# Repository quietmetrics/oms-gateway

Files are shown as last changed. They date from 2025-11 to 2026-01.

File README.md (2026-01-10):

## OMS Gateway (ESP32-C3 + CC1101)

This project is the firmware for an OMS/W‑MBus gateway running on ESP32‑C3 + CC1101.
It receives OMS telegrams via the CC1101, decodes the link‑layer structure, exposes a Web UI,
and forwards logical frames with metadata over Wi‑Fi to a backend.
The system overview below illustrates the data flow from the meter through the gateway to the backend,
then via MQTT into storage and dashboards/analytics.

### System Overview
```mermaid
flowchart LR
  classDef api fill:#d1fae5,stroke:#10b981,stroke-width:1px,color:#065f46;
  METER[OMS meter]
  subgraph GATEWAY_S[<b>Gateway]
    direction LR
    CC1101[CC1101 sub-GHz] <-->|SPI| ESP32[ESP32-C3 Wi-Fi]
  end
  METER -->|868MHz| CC1101
  subgraph BRIDGE_S[<b>Bridge]
    BRIDGE[Bridge Backend <br>FastAPI + Lobaro]
  end
  LOBARO[Lobaro API]
  LOBARO <-->|REST API| BRIDGE
  class LOBARO api;
  ESP32 -->|Wi-Fi / REST| BRIDGE
  BRIDGE -->|MQTT| STORE[Storage <br>Telegraf + InfluxDB]
  BRIDGE -->|MQTT| PROCESS_A[Real-time consumers]
  STORE -->|DB| PROCESS_B[Dashboards + analytics <br>Grafana]
```

### Key Concepts
- RF bytes are 3-of-6 coded on air; the firmware decodes and validates CRC16 blocks.
- The logical frame is CRC-free and starts at L; logical length = L+1, payload_len = L-10.
- The gateway forwards logical frames and metadata; decryption and application parsing happen in the backend.
- Parsing of decoded meter data is handled by [Lobaro](https://confluence.lobaro.com/display/PUB/wMbus+Parser), as shown in the system overview.
- The Web UI exposes live radio stats, frame metadata, and raw logical hex for external tools.

For a layer-by-layer breakdown of the OMS stack and code references see `doc/OMS_PROTOCOL_STACK.md`.

### Protocol Layers
| Protocol layers                                                                                                                               |
| --------------------------------------------------------------------------------------------------------------------------------------------- |
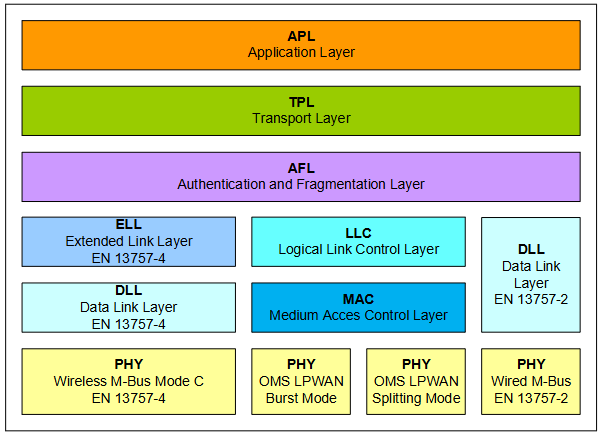
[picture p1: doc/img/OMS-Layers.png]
OMS protocol layers
|                                                                                                 |
| Diagram of the OMS stack we parse: PHY through DLL/ELL/TPL/AFL to APL, highlighting what the firmware extracts and what the backend finishes. |

### Encryption and Payload Strategy
- The gateway does not store keys and does not decrypt payloads.
- Transport/ELL/AFL parsing identifies where encrypted bytes sit in the logical frame.
- Full decoding is delegated to the backend.

### Web UI
Single-page UI for configuration and live monitoring.

| Web UI                                                                                                 |
| ------------------------------------------------------------------------------------------------------ |
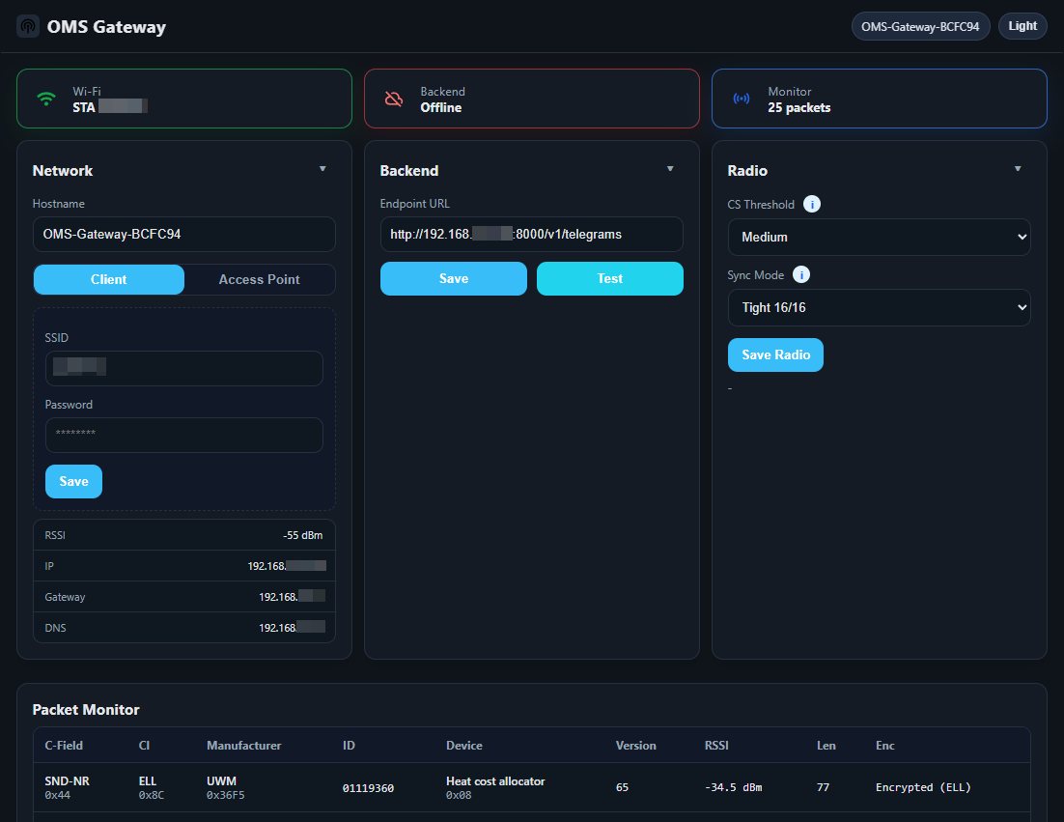
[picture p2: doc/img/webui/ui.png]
Web UI
|                                                                         |
| Main Web UI showing status cards, network/backend/radio controls, and quick device health at a glance. |

| Packet Monitor                                                                                           |
| -------------------------------------------------------------------------------------------------------- |
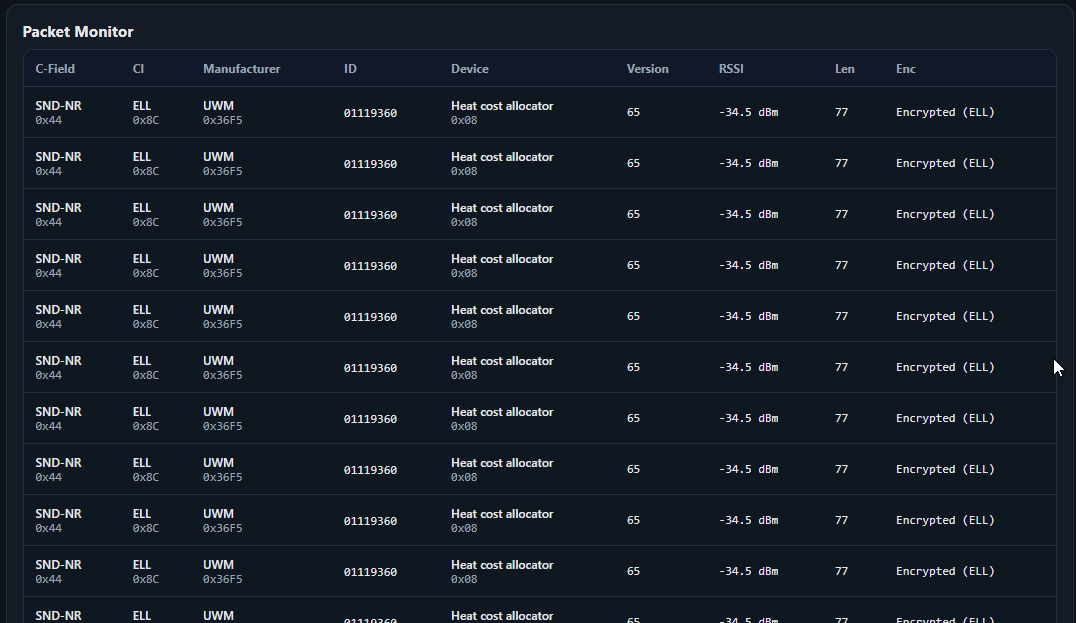
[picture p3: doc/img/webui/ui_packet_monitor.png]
Packet Monitor
|                                                    |
| Packet Monitor table with live frames, metadata, and quick indicators for encryption and signal quality. |

| Packet Details (Layers)                                                               |
| ------------------------------------------------------------------------------------- |
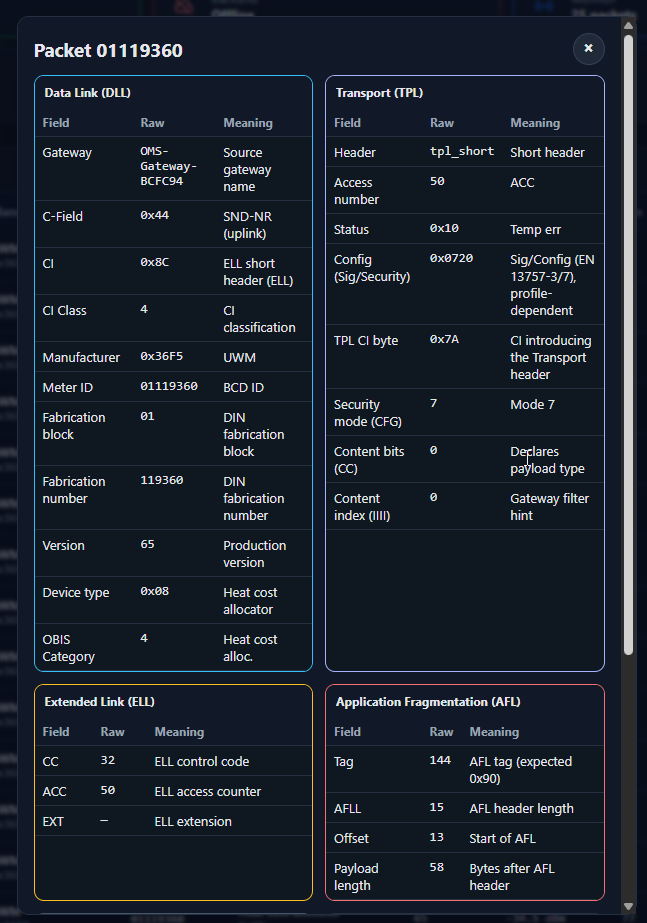
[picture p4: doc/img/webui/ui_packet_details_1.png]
Packet Details
|                               |
| Packet details dialog showing per-layer cards and parsed fields for a selected frame. |

| Packet Details (Raw)                                                           |
| ------------------------------------------------------------------------------ |
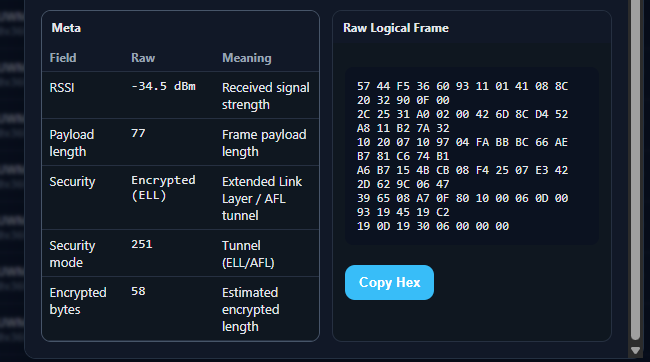
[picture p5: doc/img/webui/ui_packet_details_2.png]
Packet Details
|                        |
| Raw logical frame view with copy option for external tooling and verification. |

### Hardware
- ESP32-C3 (SuperMini form factor) + CC1101 868/886 MHz module.
- CC1101 breakout pinouts vary; use the TI datasheet as the wiring reference.

| Prototype hardware                                                                        |
| ----------------------------------------------------------------------------------------- |
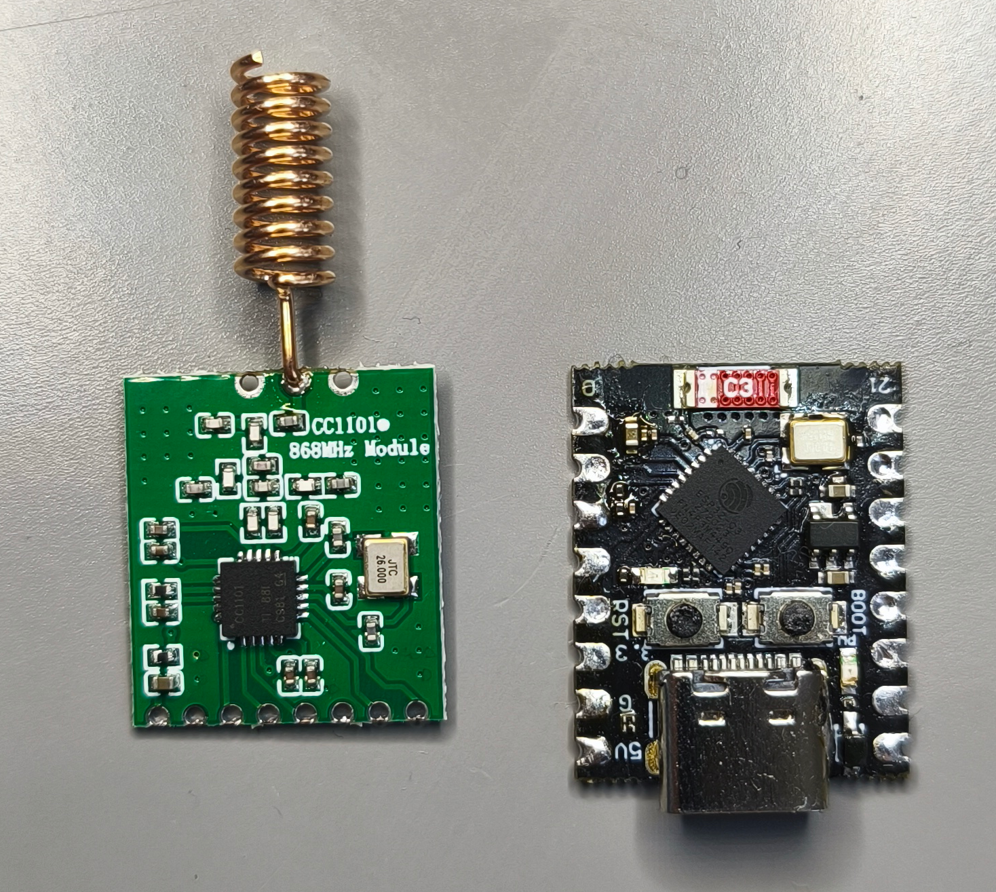
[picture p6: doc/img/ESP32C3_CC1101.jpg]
ESP32-C3 and CC1101
|                                         |
| Prototype hardware: ESP32-C3 board paired with a CC1101 module for sub-GHz OMS reception. |

| Connected prototype                                                    |
| ---------------------------------------------------------------------- |
| ESP32-C3 and CC1101 connected |
| Wiring between the ESP32-C3 and CC1101 during bring-up and RF testing. |

| Enclosure open | Enclosure with lid |
| --- | --- |
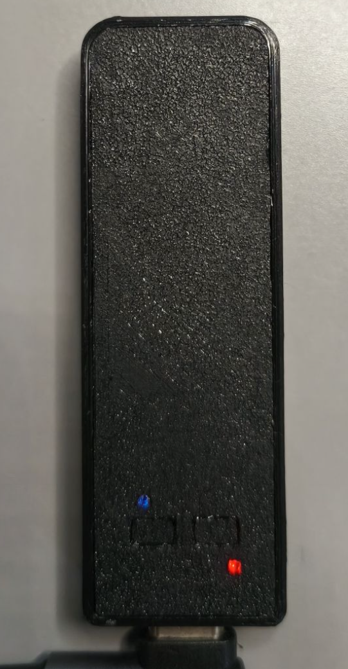
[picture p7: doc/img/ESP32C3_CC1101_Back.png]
Enclosure with lid
| Enclosure open |  |

### Requests (HTTP)
Outbound to backend (configured URL):
- Method: POST
- Content-Type: application/json
- Body example:
```json
{
  "gateway": "oms-gateway",
  "status": 0,
  "rssi": -67.5,
  "lqi": 103,
  "manuf": 3246,
  "id": "12345678",
  "dev_type": 7,
  "version": 1,
  "ci": 120,
  "payload_len": 77,
  "logical_hex": "2B44..."
}
```

Local device API (used by the Web UI):
- GET /api/status
- GET /api/packets
- POST /api/backend?url=...
- GET /api/backend/test?url=...
- POST /api/wifi?ssid=...&pass=...
- POST /api/ap?ssid=...&pass=...
- POST /api/radio?cs=...&sync=...
- See main/app/http_server.c for the full list.

### Quick build/flash
Run from repo root with ESP-IDF environment sourced:
```sh
idf.py set-target esp32c3    # one-time
idf.py build
idf.py -p /dev/ttyUSB0 flash
idf.py monitor
```
Adjust serial port as needed. Use `idf.py erase-flash` if NVS/config needs resetting.

### Repository Layout
- `main/app/`: runtime, services, Wi-Fi/backend forwarding, frame parsing, Web UI.
- `main/radio/`: CC1101 HAL, register presets, RX pipeline glue.
- `main/wmbus/`: OMS/W-MBus framing (3-of-6, CRC16), packet parsing, pipeline utilities.

### Packet Handling Flow (T-mode)
RX path (CC1101 to decoded packet):
- CC1101 strips preamble/sync and exposes 3-of-6 coded bytes in its RX FIFO.
- `wmbus_pipeline_receive` (`main/wmbus/pipeline.c`) reads the first coded bytes, decodes L-field, and sizes the packet.
- `wmbus_decode_rx_bytes_tmode` decodes the 3-of-6 stream and checks CRC16 blocks.
- If `rx_logical` is provided, CRC blocks are stripped and `frame_info` is filled for UI/backend use.

TX path (app to CC1101):
- Build a header (`wmbus_build_default_header`) or fill `WmbusFrameHeaderRaw`, then encode with `wmbus_encode_tx_packet_with_header`.
- `wmbus_encode_tx_bytes_tmode` converts raw packet bytes into 3-of-6 coded bytes.

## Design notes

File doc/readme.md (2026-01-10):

# OMS Gateway – Project Status and Key Concepts

> [!NOTE]
> This document summarizes the current state of the OMS Wireless M‑Bus Gateway
> and the main architectural ideas, from the meter in the field up to the
> dashboard.

> [!IMPORTANT]
> Repository structure update: this repo now focuses solely on the ESP-IDF
> firmware. The FastAPI backend lives in a dedicated repository
> ([oms-bridge](https://gitBridge.com/quietmetrics/oms-bridge)), ensuring both codebases can evolve
> independently while keeping their documentation close to the relevant code.

> [!TIP]
> Need a layer-by-layer breakdown of the OMS stack? See `doc/OMS_PROTOCOL_STACK.md`
> for a companion guide that mirrors OMS Volume 2 and references the codebase.

---

## 1. Goal and Scope

The OMS Wireless M‑Bus Gateway has four main goals:

* Receive **OMS Wireless Meter‑Bus frames** in the 868 / 886 MHz band with a
  **Texas Instruments CC1101 sub‑GHz transceiver (CC1101)**.
* Use an **Espressif ESP32‑C3 microcontroller (ESP32‑C3)** with Wi‑Fi as the
  central platform.
* Forward frames, metadata and encrypted payload to a **backend and database**.
* Provide a **web interface (Web UI)** for configuration and live monitoring.

Decryption and interpretation of meter readings are **not** performed on the
radio side. They are part of the **data processing pipeline** in the backend
and belong to the next development step together with the **Application Layer
(APL)** parsing.

---

## 2. End‑to‑End System Picture

### 2.1 Big Picture

```mermaid
flowchart LR
  OMS[OMS meter device]
  GW[OMS gateway]
  DB[Time series database]
  UI[Visualization dashboard]

  OMS --> GW --> DB --> UI
```

* The **OMS meter device** sends encrypted Wireless M‑Bus frames over the air.
* The **OMS gateway** receives the radio signal, decodes the protocol layers
  and forwards encrypted payload plus metadata.
* The **time series database** stores the data for long‑term analysis.
* The **visualization dashboard** shows trends, alarms and reports.

> [!NOTE] Current Build Status  
> - [x] Stable RF receive path (CC1101 HAL, Mode C timing, RSSI/LQI logging)  
> - [x] Layered parser (DLL → ELL → AFL → TPL) filling `wmbus_parsed_frame_t` for UI/backend  
> - [x] Web UI for Wi-Fi onboarding, radio presets, backend probe, live monitor  
> - [x] FastAPI backend stub ready for MQTT/InfluxDB forwarding  
> - [x] Active-low LED HAL for Wi-Fi/payload feedback on GPIO8  
> - [ ] Backend decryption + Application Layer parsing  
> - [ ] Finalize MQTT/InfluxDB bridge and RF-optimized hardware rev

### 2.2 OMS Protocol Layers

An overview of the protocol layers used in the project:

OMS protocol layers

The implementation focuses on:

* **Physical Layer (PHY)**
* **Data Link Layer (DLL)**
* **Transport Layer (TPL)** and **Extended Link Layer (ELL)**
* **Application Frame Layer (AFL)** and **Application Layer (APL)**

The gateway extracts the structure and metadata of these layers so that the
backend can apply decryption and application‑specific parsing.

### 2.3 Application Payload Strategy

OMS meters embed their readings in CI-dependent payloads (M‑Bus DIF/VIF trains,
DLMS/COSEM APDUs, SML frames, service protocols, etc.). Parsing those streams
requires a large, meter-specific knowledge base (storage slots, quantities,
descriptors). Instead of duplicating projects such as
[`wmbusmeters`](../EXAMPLE_WMBUSMASTER/wmbusmeters) on the ESP32 (which would
exceed the available flash/RAM and be hard to keep up to date), the firmware
currently forwards the entire logical frame to the backend/Web UI. The monitor
UI now exposes a raw-hex copy button so external tools can ingest exactly what
the gateway received. Full decoding is therefore expected to happen off-device
where mature, easily updateable drivers already exist.

---

## 3. Hardware Status

### 3.1 Main Components

| Component | Role in the gateway |
| --- | --- |
| **Espressif ESP32‑C3** | MCU platform with Wi‑Fi, USB‑C power, FreeRTOS runtime for radio control + Web UI. |
| **TI CC1101 (sub‑GHz)** | Frontend for OMS Mode C reception, SPI-connected with dedicated GPIO interrupts. |
| **Enclosure / CAD** | 3D-printed shell combining ESP32‑C3 + CC1101 for a repeatable lab setup. |

| ESP32‑C3 and CC1101 | Description |
| --- | --- |
| ESP32-C3 and CC1101 | First working prototype of the OMS gateway based on ESP32‑C3 and CC1101. |

> [!WARNING]
> Pinouts of low‑cost CC1101 breakout boards are inconsistent. The design uses
> the original Texas Instruments documentation as the primary reference for
> wiring and register configuration.

### 3.2 Wiring and Pinout

| ESP32‑C3 SuperMini pinout | CC1101 module pinout |
| --- | --- |
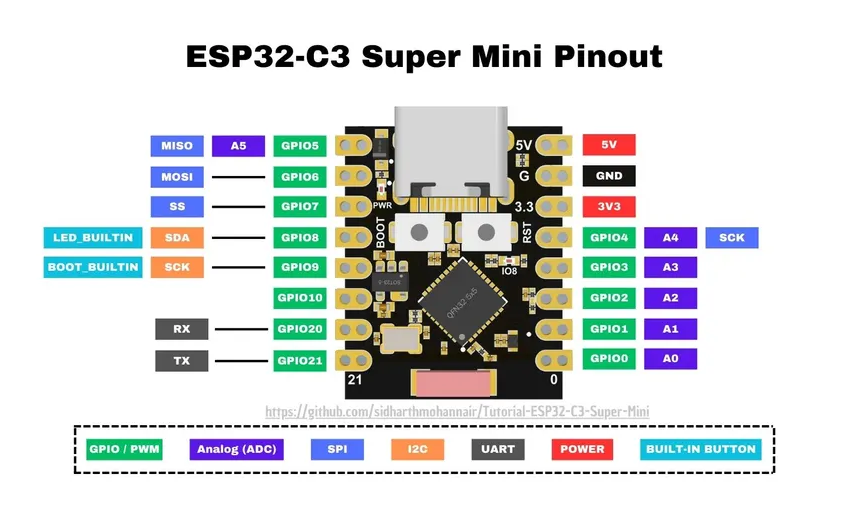
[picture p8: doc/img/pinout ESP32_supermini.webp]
ESP32-C3 SuperMini pinout
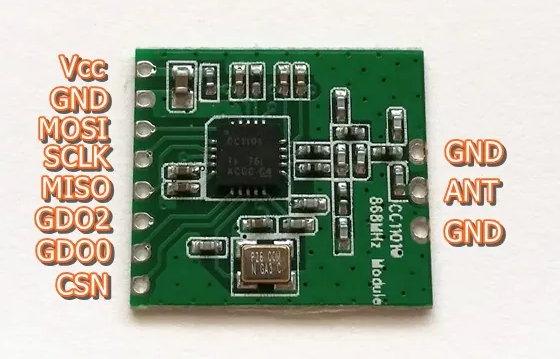
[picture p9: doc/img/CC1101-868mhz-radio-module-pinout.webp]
CC1101 module pinout
|  |  |

Relevant connections:

* **Serial Peripheral Interface (SPI)** bus: MOSI, MISO, SCLK, CSN
* **General Digital Output (GDO)** pins: GDO0 and GDO2 for interrupts and
  status signals
* **Power supply:** VCC and GND

During bring‑up a conflict with an on‑board **Light Emitting Diode (LED)** pin
was identified. That pin was initially used for the CC1101 and caused unstable
SPI behaviour. After rewiring, the SPI link is stable and the CC1101 responds
reliably.

---

## 4. Bring‑Up and Debugging

### 4.1 Arduino‑Based Sanity Check

To reduce risk, the radio path was validated with simple **Arduino‑style test
firmware**:

* [x] Initialize the Serial Peripheral Interface (SPI) and the CC1101.
* [x] Read CC1101 identification registers `PARTNUM` and `VERSION`.
* [x] Switch the CC1101 into receive mode.
* [x] Use open‑source libraries (`mfurga/cc1101` and
  `alex-icesoft/esp32_cc1101_wmbus`) for quick tests.
* [x] Observe that Wireless Meter‑Bus frames are received on air.

This confirms that wiring, basic configuration and timing are correct.

### 4.2 Logic Analyzer Investigation

A **logic analyzer** was used on SCLK, CSN, MOSI, MISO, GDO0 and GDO2 to
clarify communication problems.

| Logic analyzer on the setup | Logic analyzer signals |
| --- | --- |
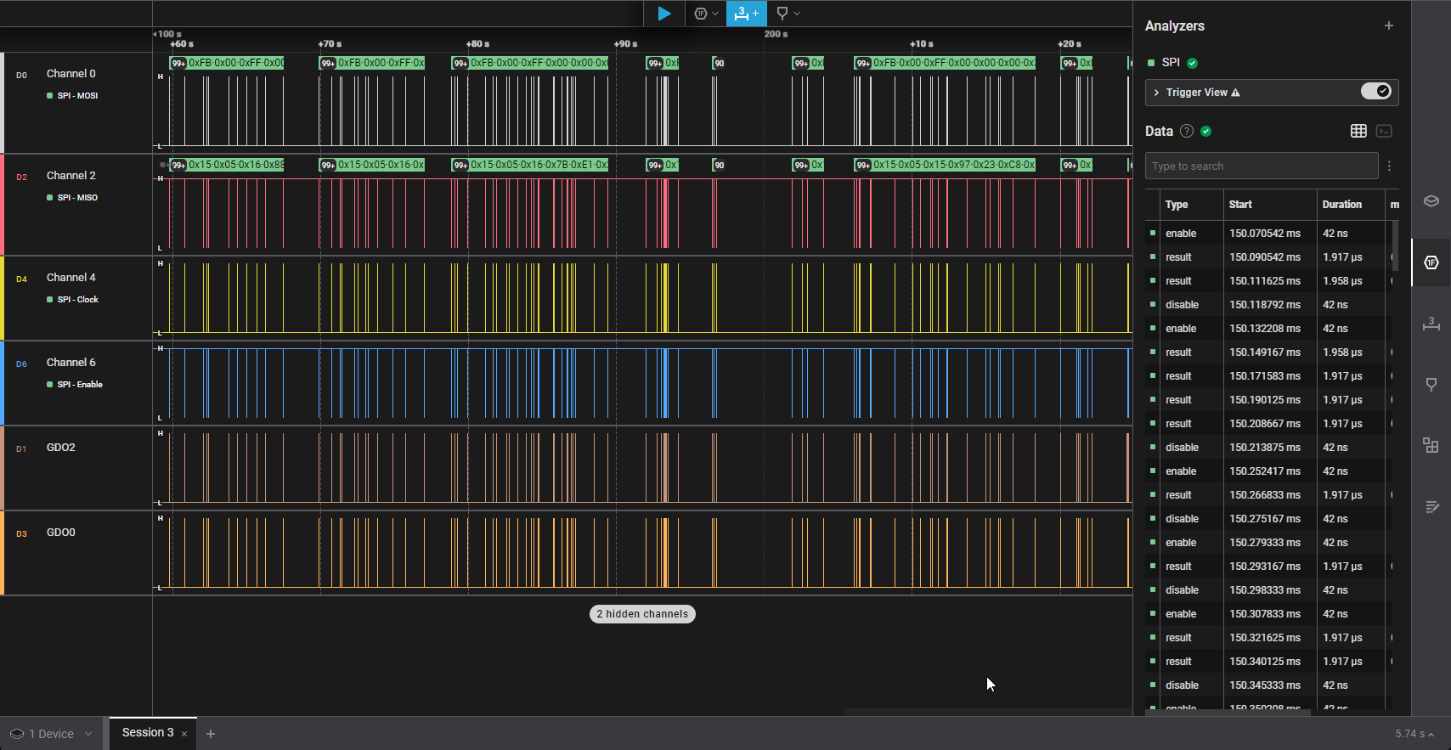
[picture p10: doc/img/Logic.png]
Logic analyzer signals
| Logic analyzer on the setup |  |

Checklist:

* [x] Chip Select (CSN) toggles cleanly around each SPI transfer.
* [x] Serial Clock (SCLK) is active only while Chip Select (CSN) is low.
* [x] MOSI and MISO show plausible data patterns.
* [x] General Digital Output (GDO) pins toggle when packets are received.

This created a **stable baseline** for further protocol work.

---

## 5. Radio Environment and Receiver Tuning

### 5.1 Operating Environment

> [!IMPORTANT]
> Dense urban RF environment (multiple OMS meters, IoT nodes, alarm radios)
> demands tight sync detection and conservative duty-cycle management to avoid
> false positives and collisions.

### 5.2 CC1101 Receiver Parameters

Three parameters of the Texas Instruments CC1101 transceiver are now used for
practical tuning:

| Setting | Options | Current choice | Effect |
| --- | --- | --- | --- |
| Automatic Gain Control (AGC) sensitivity | low or high | high | High sensitivity increases range but also increases noise; low sensitivity reduces false packets but reduces range. |
| Carrier Sense (CS) threshold | LOW, DEFAULT, MEDIUM, HIGH | DEFAULT | Defines when the channel is considered busy. LOW is very sensitive, HIGH ignores weaker signals. |
| Sync Word correlation mode | DEFAULT, TIGHT, STRICT | TIGHT | A more strict correlation mode reduces false detections at the cost of dropping weak frames. |

Current configuration (TIGHT Sync Word mode and DEFAULT Carrier Sense level)
provides a good balance between robustness and false positives in this
environment.

---

## 6. Mechanical Prototype

A simple **three‑dimensional (3D) printed enclosure** was designed to combine
the ESP32‑C3 board and the CC1101 module into a single unit.

| Enclosure open | Enclosure with lid |
| --- | --- |
| Enclosure open | Enclosure with lid |

Characteristics:

* Provides safe mechanical mounting and a reproducible lab setup.
* Offers easy USB‑C access for power and flashing.
* Is sufficient for tests but not yet optimised for radio frequency behaviour
  because some cables cross the ESP32‑C3 Wi‑Fi antenna area.

A later revision is planned with a dedicated Printed Circuit Board (PCB) and a
radio‑frequency clean layout.

---

## 7. Gateway Firmware and Data Flow

### 7.1 End-to-End Data Flow

The former firmware-only decoding overview has been broadened into the complete
data journey: from RF capture on the gateway through backend processing to
storage and analytics. Each area owns a distinct responsibility so firmware,
backend, storage, and visualization can evolve independently while keeping the
hand-offs explicit.

```mermaid
flowchart LR
  GATEWAY[<b>1. Gateway</b><br>ESP32-C3 + CC1101 firmware] -->|Wi-Fi / REST| Bridge[<b>2. Bridge Backend</b><br>FastAPI + wmbusmeters]
  Bridge -->|MQTT| STORE[<b>3. Storage</b><br>Telegraf + InfluxDB]
  Bridge -->|MQTT| PROCESS_A[<b>4.1 Real-time MQTT consumers</b>]
  STORE -->|DB| PROCESS_B[<b>4.2 Historical dashboards & analytics</b>]
```

1. **Gateway (Firmware)**
   * CC1101 + ESP32-C3 capture the RF signal (OMS Mode C), perform demodulation,
     whitening removal, 3-of-6 decoding, CRC verification, and frame boundary
     detection.
   * The firmware assembles a structured frame description: PHY stats (RSSI/LQI),
     DLL addresses, TPL/ELL security fields, AFL offsets, and the encrypted
     Application payload bytes. It does **not** decrypt or interpret the payload.
   * Frames and metadata are exposed to the Web UI for live monitoring and
     forwarded to the backend via Wi-Fi using the REST endpoint.

2. **Bridge (Backend)**
   * A dedicated FastAPI service (leveraging `wmbusmeters` tooling) receives frames
     from the gateway, runs security profile checks, performs AES decryption,
     validates MICs, and decodes the Application payload into typed fields
     (e.g., DIF/VIF values).
   * Parsed readings, diagnostic data, and events are published on MQTT topics so
     downstream services can subscribe without tight coupling to the API; this
     MQTT output is what feeds the storage layer.

3. **Storage**
   * Telegraf subscribes to the backend MQTT topics, normalizes the decoded data, and
     writes time-series metrics plus tags (meter ID, location, type) into
     InfluxDB.
   * Retention policies keep historical data accessible for trend analysis while
     bounding storage usage.

4. **Processing & Visualization**
   * This stage splits into fast reactions on MQTT events and deep dives on the
     stored history so operational alerts and long-term analytics stay decoupled.
   1. **4.1 Real-Time MQTT Consumers** – Automation services or lightweight workers
      subscribe directly to the Bridge’s MQTT topics for immediate actions (alerts,
      actuator commands, anomaly triggers) without waiting for storage.
   2. **4.2 Historical Dashboards & Analytics** – Grafana, notebooks, or
      data-science jobs query InfluxDB (optionally blending cached MQTT snapshots)
      to build dashboards, reports, batch analytics, or export data to billing/ERP
      systems without touching the gateway firmware.

### 7.2 Role of Encryption

Encryption is treated as part of the **data processing pipeline**:

* The gateway does **not** store symmetric keys and does **not** perform
  decryption of meter readings.
* The gateway identifies where the encrypted payload is located in the frame
  using the Transport Layer, Extended Link Layer and Application Frame Layer.
* The backend receives the encrypted payload plus the necessary metadata to
  perform decryption and Application Layer parsing.

The next development step is to connect the identified security configuration
fields to a concrete decryption implementation in the backend and to implement
correct Application Layer parsing.

### 7.3 OMS Protocol Stack in This Project

The OMS / Wireless M‑Bus stack inside this repository closely mirrors Volume 2 of the OMS specification:

1. ⚙️ **Physical Layer** – CC1101 runs Mode C timings (preamble, 3-of-6 coding) and enforces duty-cycle limits per meter type. LPWAN annex parameters are tracked for future range experiments.
2. 📶 **Link / Extended Link Layer** – `main/wmbus/pipeline.c` verifies C/L-fields, addresses (LLA + ELLA), hop bits and synchronous timing, handing off clean payloads plus RSSI/LQI.
3. 🧷 **Authentication & Fragmentation Layer (AFL)** – Fragment headers, MACs and Ki-flags are parsed so Security Profiles B–D can be validated even if payload stays encrypted.
4. 📬 **Transport Layer (TPL)** – CI-field, Access Number, Status bits and Configuration Field are decoded and surfaced to the UI/backend, enabling command workflows and Application Error reporting.
5. 📦 **Application Protocols (backend)** – The firmware forwards logical frames verbatim; decoding DIF/VIF trains, DLMS, or SML payloads now happens in the FastAPI/wmbusmeters backend using [wmbusmeters](https://gitBridge.com/wmbusmeters/wmbusmeters).

For a detailed walkthrough of each layer, message type, and how the code maps to OMS Volume 2 see **`doc/OMS_PROTOCOL_STACK.md`**.

---

## 8. Web Interface

The ESP32‑C3 microcontroller hosts a **single‑page Web UI** that allows
configuration and monitoring in a standard web browser.

### 8.1 Status Overview

Full UI

The top bar shows:

* Network status (Access Point mode or Station mode, Received Signal Strength
  Indicator (RSSI), Internet Protocol (IP) address).
* Backend connectivity (reachable or not reachable).
* Number of recently received frames.

### 8.2 Configuration Sections

| Section | Purpose |
| --- | --- |
| **Network** | Configure Wi‑Fi STA/AP credentials, hostname, and IP variables. |
| **Backend** | Set HTTP/MQTT endpoints, run reachability probe, and view status. |
| **Radio** | Adjust CC1101 CS thresholds, sync correlation, and monitor live stats. |

### 8.3 Packet Monitor and Details

Packet Monitor

The Packet Monitor shows for each received frame:

* Control field, Communication Identification field, manufacturer code, meter
  identification, version and device type.
* Radio meta data such as Received Signal Strength Indicator and frame length.
* A hint whether the payload is encrypted.

A details dialog displays one card per layer (Data Link Layer, Transport
Layer, Extended Link Layer, Application Frame Layer and general metadata). Only
layers that exist in the concrete frame are shown.




The Web UI does **not** display decrypted measurement values. It focuses on
structure, addresses and radio quality.

---

## 9. Progress Checklist ✅

### 9.1 Implemented

| ✅ Delivered | Notes |
| --- | ----- |
| Hardware bring‑up (ESP32‑C3 + CC1101) | SPI + GPIO paths validated, enclosure available. |
| Stable SPI comms | Logic analyzer traces confirm reliable transfers/interrupts. |
| Live RF reception | Real OMS traffic decoded in-city with RSSI/LQI logged. |
| Layered decoding | PHY → DLL/ELL → AFL/TPL → metadata pipeline implemented. |
| Web interface | Handles Wi‑Fi/backend/radio configuration + monitor. |

### 9.2 Next Steps

| 🧭 Focus | Description |
| --- | --- |
| Backend security parsing | Interpret CF/AFL security bits in FastAPI service. |
| Payload decryption | Implement AES/TLS handling + key management on backend. |
| Application parsing | Decode mandatory OMS data points (Annex B) downstream. |
| Hardware rev | Improve RF layout with dedicated PCB and clean antenna path. |
| QA & docs | Expand automated tests and contributor guidance. |

---

## 10. References

* Texas Instruments CC1101 datasheet.
* Texas Instruments application note SWRA234 with example code for CC1101.
* Open‑source CC1101 and Wireless Meter‑Bus libraries used for initial
  validation (`mfurga/cc1101` and `esp32_cc1101_wmbus`).

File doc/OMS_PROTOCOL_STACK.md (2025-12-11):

# OMS / Wireless M-Bus Protocol Stack Guide

This guide condenses the OMS Volume 2 Primary Communication specification (Issue 5.0.1, Dec 2023) and maps each layer to the firmware that lives in this repository. Use it as a beginner-friendly reference when decoding captured frames, creating new packet handlers, or explaining OMS/W‑M‑Bus behavior to other contributors.

## 1. Stack Overview (Vol.2 §§2–4)
- **Physical Layer** – Either wired M‑Bus per EN 13757‑2 or wireless mode C/OMS‑LPWAN per EN 13757‑4 / Annex Q. Defines media, frequencies, timing, and synchronous vs. asynchronous transmission rules.
- **Data Link + Link Control** – Frame Format A (DLL + optional Extended Link Layer) for mode C and Frame Format C (MAC/LLC) for OMS‑LPWAN. Carries the C‑field (message type), L‑field, transmitter/receiver addresses, and hopping/availability bits.
- **Authentication & Fragmentation Layer (AFL)** – Optional shim that adds fragmentation headers, message counters, MACs, and key hints whenever security profiles B–D or long messages are used.
- **Transport Layer (TPL)** – CI‑field plus a fixed header (none/short/long) containing Access Number, Status, and Configuration information that explains the application protocol to follow (M‑Bus, DLMS/COSEM, SML, management services).
- **Application Protocols** – M‑Bus data points (Annex B), DLMS (EN 13757‑1 / 62056‑6‑1), SML, and service-specific protocols (clock sync, application error, security management, image transfer, etc.) defined in Annex M.
- **Security & Key Management** – Security profiles A–D map onto security modes 0/5/7/10/13 and dictate encryption (AES‑CBC, AES‑CCM, TLS), MAC types, and key sources (persistent vs. derived).

```mermaid
graph TB
    subgraph Physical
        PHY[Physical Layer<br/>EN 13757-2 / -4 / Annex Q]
    end
    subgraph Link
        LINK[Data Link + Extended Link Layer<br/>C-field · L-field · addresses]
    end
    subgraph AFLayer
        AFL[AFL<br/>fragmentation + MAC]
    end
    subgraph Transport
        TPL[Transport Layer<br/>CI · Access Number · Status · CF]
    end
    subgraph Application_Services
        APP[Application Protocols<br/>M-Bus · DLMS · SML · Services]
    end
    subgraph Security
        SEC[Security Profiles / Keys<br/>Modes 0 / 5 / 7 / 10 / 13]
    end
    PHY --> LINK --> AFL --> TPL --> APP
    SEC -. protects .-> LINK
    SEC -. protects .-> AFL
    SEC -. protects .-> TPL
    SEC -. protects .-> APP
    LINK -. control + addressing .-> TPL
```

> **Repository cross-reference** – `main/wmbus/` covers PHY/Link decoding, `app/wmbus/frame_parse.c` interprets Link/TPL/Application headers, `app/wmbus/packet_router.c` fans events out, `app/net/backend.c` forwards decoded payloads, and `app/radio/radio_config.c` configures CC1101 timing per the physical layer rules.

## 2. Physical Layer Essentials (Vol.2 §4)
- **Wired M‑Bus**: Two-wire, polarity independent bus per EN 13757‑2. Slaves include a 430 Ω series resistor to cap short-circuit current at 100 mA. Gateways power/read sensors in pull mode and must accept L‑fields ≤ 255 bytes. Mini-Master capability is the minimum baseline.
- **Wireless mode C (C1/C2)**: Operates in 868–870 MHz ISM bands with a recommended 0.02 % hourly duty cycle. End devices transmit periodically (push). Bidirectional communication happens within short receive slots directly after each transmission (Frequent Access Cycle). Synchronous transmissions use the S‑bit, Access Number, and deterministic timing; asynchronous transmissions cover alarms, ACK/NACK, and installation frames.
- **OMS‑LPWAN (Annex Q)**: Adds MAC scheduling, Forward Error Correction, and frame aggregation for long-range/battery-friendly deployments. Access options (MElements) advertise when a device can listen; special codes represent “no receive window” (pure push) or “always on” (mains powered).
- **Update cadence**: Table 8 enforces minimum data granularity for billing—e.g., electricity data every 15 min, gas/water every hour, heat/cooling every 24 h, heat cost allocators every 240 min. Mode C is expected to refresh at least each synchronous transmission, while LPWAN may batch multiple periodical values into a compact profile (formula `N_DP = TU / DG * 2`).

## 3. Addressing and Link Layer (Vol.2 §§3 & 5)
### 3.1 Address types
- **Primary Address (PA)** – 1‑byte wired M‑Bus slave address (1–250 valid, 0 unconfigured, 251–255 special). Selected via DL layer when no secondary addressing is required.
- **Secondary Address / ALA (Application Layer Address)** – 8‑byte structure (manufacturer ID, version, device type, serial). Immutable per device, globally unique, and transmitted in every message that uses a long TPL header. Primary address 253 announces that secondary selection is in use.
- **Link Layer Address (LLA)** – Wireless transmitter address embedded in Frame Format A. Uniquely assigned by manufacturers for all radio devices.
- **Extended Link Layer Address (ELLA)** – Destination address carried in the long ELL (CI = 0x8E). Required when (1) talking to unallocated devices or service tools, (2) responding to a request containing ELLA, (3) fragmenting messages (because only the first fragment has the ALA), or (4) addressing RF adapters.
- **DIN Address** – Printable format (OBIS category + ASCII manufacturer ID + fabrication block + serial) that maps 1:1 to secondary addresses.

```mermaid
flowchart LR
    PA[Primary Address<br/>1 byte · wired only]
    ALA[Application Layer Address<br/>8 bytes · manuf + ID + type + version]
    LLA[Link Layer Address<br/>wireless TX]
    ELLA[Extended Link Layer Address<br/>wireless RX]
    DIN[DIN Address<br/>OBIS category + manuf ASCII + block + serial]
    PA -. selects .-> ALA
    ALA <--> DIN
    LLA --> ALA
    ELLA --> LLA
    ELLA -. required for .-> Fragmentation
    ALA -. required for .-> Encryption
```

### 3.2 Frame Format A (mode C)
- **Data Link Layer** – Fixed 10‑byte header (without CRC) carrying the L‑field (length) and C‑field. Bidirectional devices must support L ≤ 155; security profile C and OTA updates must honor L ≤ 255.
- **Extended Link Layer** – Short ELL (CI = 0x8C) adds only the Communication Control (CC) field; long ELL (CI = 0x8E) adds receiver Identification Number, Manufacturer ID, Version, and Device Type. CC bits: `B` (bidirectional available), `A` (access demand), `S` (synchronous transmission), `R/H` (repetition flags), `D` (downlink demand). When both CC and TPL Configuration fields exist, only CC bits are authoritative.
- **Hop control** – Repeaters set `H=1` and recalc CRC; senders keep `H`/`R` at 0. Hop bits also live in LPWAN LC[1] fields.

### 3.3 Frame Format C (OMS‑LPWAN)
- LLC combines transmitter (TXA) and receiver (RXA) addresses, removing the need for a separate ELL. LC[0] controls whether TXA/RXA are present, LC[1] embeds hop and accessibility flags, and MAC MElements advertise access options and session control.

### 3.4 Timing, credits, and access (Vol.2 §4.3)
- **Synchronous vs. asynchronous**: Synchronous messages set `S=1` and use deterministic Access Number increments (`ACC`), enabling gateways to predict RX slots (Figure 16). Asynchronous traffic (alarms, installations, commands) keeps `S=0` but still increments ACCESS according to EN 13757‑7.
- **Frequent Access Cycle (FAC)**: Mode C bidirectional devices must open the receive window defined in EN 13757‑4 §12.6.3.3 after each synchronous uplink. Gateways close the FAC with `SND‑NKE`. LPWAN uses a session control bit in the MAC downlink (Annex Q §3.3.5).
- **Credits (Tables 11–13)**: Each received or transmitted datagram consumes credits (e.g., receive SND‑UD → 2 credits, REQ‑UD1/2 → 1, send RSP‑UD → 1). Devices must offer at least 240 credits within the duty-cycle budget for mode C (120 for UL‑B4, down to 1–2 for S‑modes) and replenish counters every 2 h. Credits can accumulate up to 4000, but devices may pause communication after consuming 240 credits in 12 h even if credits remain.
- **Maximum access delay**: Table 12 caps the time between the first transmission without access and the first usable access opportunity (12–72 h depending on radio mode).

### 3.5 Link-layer message types (Vol.2 Tables 15 & 16)

| Direction | Message type | C‑field | Usage |
|---|---|---|---|
| Master → slave | `SND-NKE` | 0x40 | Link reset / announce capability to receive installation frames |
| Master → slave | `SND-UD2` | 0x43 | Command with mandatory response (not for fragmented messages) |
| Master → slave | `SND-UD` | 0x53 / 0x73 | Command / data download (FCB/FCV per EN 60870‑5‑2) |
| Master → slave | `REQ-UD1` | 0x5A / 0x7A | Alarm request (Class 1) |
| Master → slave | `REQ-UD2` | 0x5B / 0x7B | Data request (Class 2) |
| Master → slave | `CNF-IR` | 0x06 | Confirms successful installation |
| Slave → master | `SND-NR` | 0x44 | Spontaneous/periodic data (dynamic or static payload) |
| Slave → master | `SND-IR` | 0x46 | Installation data (externally triggered) |
| Slave → master | `ACC-NR` | 0x47 | Empty access window, keeps FAC alive |
| Slave → master | `ACC-DMD` | 0x48 | Access demand (alerts pending) |
| Slave → master | `ACK` | 0x00/0x10/0x20/0x30 | Acknowledge commands and REQ-UD1 |
| Slave → master | `NACK` | 0x01/0x11/0x21/0x31 | Persistent link-layer error (CRC already validated) |
| Slave → master | `RSP-UD` | 0x08/0x18/0x28/0x38 | Response with application data |

> Every master frame listed above must be answered (ACK, NACK, RSP‑UD, etc.) even if it is a duplicate. Gateways alternate FCB whenever they change the Gateway Access Number.

```mermaid
sequenceDiagram
    autonumber
    participant Gateway
    participant Device
    Gateway->>Device: SND-NKE (0x40)\nReset link / ready for install
    Device-->>Gateway: SND-IR / SND-NR\nInstallation or periodic data
    Gateway->>Device: REQ-UD2 (0x5B)\nRequest Class 2 data
    Device-->>Gateway: RSP-UD (0x08)\nApplication payload
    Gateway->>Device: SND-UD (0x53)\nCommand (e.g. config)
    Device-->>Gateway: ACK / RSP-UD\nStatus + response data
    Note over Gateway,Device: FAC (Frequent Access Cycle) stays open while\nAccess Number increments synchronously
    Gateway->>Device: SND-NKE\nTerminate FAC / free credits
```

### 3.6 Repeaters and gateway duties
- **Unidirectional repeaters** retransmit only `SND-NR`/`SND-IR` frames with `H=0`/`R=0`, delay 5–25 s, and emit `SND-NKE` after echoing an installation frame to tell service tools that the path is available.
- **Gateways** must rate-limit requests using the credit model, support maximum frame lengths, issue `SND-NKE` when an installation frame with `H=0` is heard, and run the collision-avoidance procedure of Annex I if multiple gateways target the same device.

## 4. Authentication & Fragmentation Layer (Vol.2 §6)
- **When to use** – Always for fragmented messages, for any payload protected by security profile B or D, for selected profile C messages (per Annex F), and whenever the KI‑flag is set.
- **Fields**:
  - `AFL.MCL` – Includes the AT subfield; OMS mandates AT = 5 (AES‑CMAC‑128 truncated to 8 bytes). Gateways should also accept AT = 6/7 (12 or 16‑byte MACs).
  - `AFL.KI` – Advertises key information. Devices track a KI‑flag and keep including AFL.KI in `RSP-UD` until the flag is cleared.
  - `AFL.MCR` – Message counter reference required for security profile B and some profile C modes; ties into the transport-layer message counter (Vol.2 §9.2.5).
  - `AFL.MAC` – Only present in the last fragment because OMS authenticates the whole message, not fragment subsets.
  - `AFL.ML` – Total message length (limit 16 kB). Omit for unfragmented datagrams.
- Missing or malformed AFL sections in `SND-UD*` commands must raise an Application Error (Vol.2 §8.8).

## 5. Transport Layer (Vol.2 §7)
### 5.1 Header types
- **No TPL header** – Wired M‑Bus, unencrypted; Application Protocol follows immediately after the CI field.
- **Short TPL header** – Wireless-only; uses Link Layer Address as device identifier.
- **Long TPL header** – Contains the full Application Layer Address so that wired links can encrypt data or external adapters can ride along. Required whenever encryption, fragmentation, or RF adapters are in play.

### 5.2 Core fields
- **CI‑field** – First byte after Link Layer that selects the Transport structure and the Application Protocol/service (Annex Table 1). Examples: CI = 0x7A for REQ‑UD class 2, CI = 0x78 for M‑Bus data, CI = 0x60 for SML, CI = 0xB1 for Application Select protocol, CI = 0xC0+ for security/info transfer. Frame building code must pick the CI before encoding the remainder.
- **Access Number (TPL‑ACC)** – Distinct from the Link Layer Access Number (LL‑ACC). Gateways embed an LL‑ACC in `SND*` requests; slaves mirror it in responses. The TPL‑ACC increments with each new payload (Vol.2 §7.2.2). Asynchronous frames keep `S=0` but still bump ACC per Figure 16.
- **Status byte** – Bits `b1 b0` describe command state: `00` = no error, `01` = application busy (gateway should poll again), `10` = application error (gateway should issue `REQ-UD2` to fetch the Application Error Protocol), `11` = abnormal condition/alarm (self‑initiated only). The code updates the status bits whenever it produces a new application response.
- **Configuration Field (CF)** – Declares the security mode (0, 5, 7, 10, 13), the number of encrypted bytes (`N`), content bits (`CC`), and optional link control bits (when lower layers do not carry them). Mode‑specific extensions exist:
  - Mode 5 (security profile A/B) uses AES‑128‑CBC with optional CC bits.
  - Mode 7 (profile B) adds CMAC; the AFL supplies MAC references.
  - Mode 10 (profile D) uses AES‑128‑CCM plus an extension (Table 23) carrying KeyID (`K`), derivation selector (`D=01b`), Auth Tag length (`O=01b` for 8 bytes), optional KeyVersion (`V`), and Content Index bits (`I`).
  - Mode 13 (profile C) wraps TLS 1.2. CF extension states the Protocol Type; the TLS header itself exposes record lengths and version.
- **Content Index (`IIII`)** – Lets gateways filter messages without decrypting them (Table 26): `0000` legacy, `0001` mobile readout, `0010` fixed network, `0011` consumer info, `0100–0111` manufacturer specific. CC = 01b (additional data) reserves other values (Table 27). Only security profiles B/D carry content index bits.
- **Link-control duplication** – If ELL/LLC/MAC do not expose `B/A/S/R/H`, CF must. Otherwise set them to 0 and rely on the lower layer.
- **TPL presence** – Table 28 lists which message types must include a TPL. Wireless frames with encryption always need it; fragmented sequences carry TPL only in the first downlink and last ACK.

## 6. Application Protocols & Data Model (Vol.2 §8)
### 6.1 Message state machines
- **SND-IR** – Triggered manually (button/service tool). Sends installation data several times; gateway replies with `SND-NKE` or `CNF-IR`.
- **SND-NR / ACC-NR** – Periodic push. “Dynamic” payload contains consumption data, “Static” contains management metadata, and `ACC-NR` advertises empty slots between them.
- **REQ-UD1 / ACK** – Requests alert data. Devices without alarm support still ACK but send no payload.
- **REQ/SND-UD2 flow** – Gateways send `SND-UD` or `REQ-UD2`. Devices answer with `RSP-UD` in one of four states (standard response, selected response, command response, or error). Events such as “command successful”, “command failed”, “application select”, “timeout” drive the state machine (Tables 37–38).

### 6.2 M‑Bus Application Protocol
- **OMS Data Point List (Annex B)** – Defines mandatory (`M`), alternative (`Ax`), conditional, and optional (`O`) data points by DIB/VIB coding. Every device must emit all mandatory points and at least one alternative for its Device Type. Duplicate DIB/VIB combinations within a message are forbidden.
- **Update obligations** – Wireless devices must include obligatory points in SND‑NR frames according to Table 39 (content bit combinations). If devices send additional data under CC = 01b (extra fixed-network payload), they may omit obligatory points there but still provide them elsewhere.
- **Specific data points** – Use DP2! (`Averaging Duration`) when averaging windows differ from transmission intervals, DP1! (`Actuality Duration`) for measurements that lag behind transmission, DP3! (`Nominal transmission period`) in installation frames, MM2!/MM3! for error flags, MM1! for reception/noise level, ID6! for message sequence numbers, ID7!/ID8! for DIN addresses. Sensors with Device Type 1Fh must also send their sub-device type (ID11!).
- **Descriptors (Annex K)** – Provide human-readable meanings for storage/tariff/subunit numbers (e.g., “Storage 2 = monthly values”). Required whenever the OMS-DPL lists a descriptor as mandatory.
- **OBIS mapping** – Annex A maps OMS data points to OBIS codes so that gateways can convert M‑Bus payloads into DLMS/SML objects. Devices sending non-standard points should include the OBIS declaration themselves (M‑Bus Annex H.3).

### 6.3 Other protocols and services
- **DLMS/COSEM** and **SML** – Selectable via CI‑field; gateways must be able to parse at least the data points relevant to their function.
- **Service protocols (Annex M)** – Alarm (mandatory for 2‑way), Application Error (Vol.2 §8.8), Application Select (§8.10), Clock Synchronisation (UC‑04), Image Transfer (UC‑05), Network Management, Security Information Transfer, Security Management (required for TLS mode 13). CI values live in Table 1.

### 6.4 Device types (Vol.2 Tables 2–4)
- Certifiable OMS device types cover electricity, gas, heat, water, heat cost allocators, cooling, combined meters, pressure devices, alarm sensors, sensor hubs, waste water meters, breakers, valves, repeaters, and adapters.
- Other OMS devices include customer displays, communication controllers, and repeaters that may not undergo OMS‑CT.

## 7. Security Profiles & Key Management (Vol.2 §9)
### 7.1 Profiles (Table 43)

| Profile | Security mode | Encryption | Authentication | Key material |
|---|---|---|---|---|
| None | 0 | None | None | — |
| A | 5 | AES‑128‑CBC | None (`AT=0`) | Persistent symmetric key (KeyID per Table 45) |
| B | 7 | AES‑128‑CBC | CMAC‑128 (8‑byte tag via AFL) | Ephemeral symmetric key derived from persistent key |
| C | 13 | TLS 1.2 | TLS HMAC + CMAC during handshake | ECC key pair (256/384 bit) + derived symmetric keys |
| D | 10 | AES‑128‑CCM | CCM 8‑byte tag | Ephemeral symmetric key (derived), KeyVersion optional |

Mode 0 is also mandated for service frames (`REQ-UD*`, ACK/NACK, ACC-*, `SND-NKE`, `CNF-IR`) so that they are always processable.

### 7.2 Required support (Table 44)
- **Wireless unidirectional** – Profile A and optionally B or D on both ends.
- **Wireless bidirectional** – At least profiles A and B on devices and gateways; profile D (and optionally C) when national laws require stronger security.
- **Wired** – May use “no security”, profile A, or profile B/D/C depending on installation.
- Manufacturers must declare supported profiles. Devices cannot autonomously change their configured profile; updates happen through authorized configuration procedures.

### 7.3 Keys and identifiers
- **KeyID (Table 45)** – Identifies the purpose of each persistent key (e.g., 0x00 = Master Key). Replacing a key uses the same KeyID but a new KeyVersion.
- **Persistent vs. ephemeral keys** – Persistent keys are provisioned (e.g., during installation). Ephemeral keys are derived via the Key Derivation Function (DC constants in Table 46) per direction (device→gateway uses `Kenc`, gateway→device uses `Lenc`).
- **Mode‑10 extensions** – Field `K` selects the KeyID, `D` selects the derivation method (fixed 0x01 for OMS), `O=01b` enforces an 8‑byte authentication tag, `V` toggles inclusion of KeyVersion, and `I` repeats the Content Index bits.

## 8. Putting It Together for This Repository
- **PHY / CC1101 (`main/radio/`)** – Configure per Vol.2 §4 (mode C timing, duty cycle, synchronous scheduling). RX pipeline (`main/wmbus/pipeline.c`) reads 3‑of‑6 coded bytes, validates CRC blocks, and feeds decoded frames up the stack.
- **Link and addressing (`app/wmbus/frame_parse.c`)** – Parses C‑field, L‑field, Link Layer/ELL addresses, synchronous bits, hop information, and Access Numbers. Make sure long ELL data is retained when fragments or RF adapters are detected.
- **Authentication & security (`app/wmbus/parsed_frame.c`, `app/services.c`)** – Store AFL data (MCR, MAC) and the Configuration Field so that backend services can evaluate security profiles, content bits, and required keys.
- **Transport/Application (`app/wmbus/frame_parse.c`, `app/wmbus/packet_router.c`)** – Extract CI‑field, TPL header, status byte, configuration fields, and forward the application payload to the UI/backend. Keep track of the Application Error state machine so the status bits match Table 17.
- **Data model (`doc/readme.md`, `doc/OMS_PROTOCOL_STACK.md`, `doc/Research/...`)** – When adding new meters, consult Annex B (OMS‑DPL) to ensure the correct DIB/VIB codes, descriptors, and OBIS mappings. The web UI should expose the key data points (obligatory + conditional) and indicate alarms/application errors.
- **Networking (`app/net/wifi.c`, `app/net/backend.c`)** – Ensure Wi‑Fi connectivity state drives status LEDs and that backend forwarding includes manufacturer/manufacturer IDs, Access Numbers, status bits, and content indices so downstream services can honor the OMS contract.

## 9. How to Navigate the Spec
1. **Start with Vol.2 §§3–5** to understand addressing, link formats, credits, and message types. Mirror every parsed field in `wmbus_parsed_frame_t`.
2. **Consult §6 when you see AFL headers** (e.g., fragmented firmware updates, security profile B). The AT subfield and KI‑flag determine how many bytes you have to read.
3. **Use §7** whenever you need to interpret Access Numbers, status bits, or configuration fields. Table 28 tells you whether the TPL should exist in a given datagram.
4. **Dive into §8 + Annex B/K** for application payloads. The OMS Data Point List is the authoritative source for DIB/VIB encodings, descriptors, and OBIS mappings.
5. **Review §9 + Annex F** before implementing encryption/authentication or key provisioning. The security profile you select governs which headers, MACs, and keys are mandatory.

Armed with this map you can trace a captured RF burst all the way from CC1101 bytes to the JSON payload our FastAPI backend expects, while remaining faithful to the Open Metering System specification.

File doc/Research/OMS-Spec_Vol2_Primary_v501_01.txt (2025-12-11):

Open Metering System
Specification
Volume 2
Primary Communication
Issue 5.0.1 / 2023-12
RELEASE
Â© Open Metering System Group e.V., 2023
Open Metering System Specification Vol.2
â
Primary Communication
Issue 5.0.1 / 2023-12 (RELEASE)
Document History
Version Date
Comment
Editor
1.0.0
1.0.1
1.0.2
2008-06-27 First
final Version
2008-07-01 Editorial
Revision
U. Pahl
U. Pahl
H. Baden
2008-07-21 Some
format adoptions; table index added; content
index limited to structure level 3.
1.0.3
2009-02-25 Correct
mistake in Table 10
Add changes for 2nd Version
U. Pahl
1.0.4
1.0.5
1.0.6
1.0.7
1.0.8
2009-05-13 Revision
in AG1
AG1
2009-05-30 Add
changes for 2nd Version
2009-06-11 Update
Annex
U. Pahl
U. Pahl
U. Pahl
U. Pahl
2009-06-30 Changes
based on protocol#23
2009-07-03 Last
changes of online review; update Annex A;,L and
M, editorial review
1.0.8
1.0.9
2009-07-05 Editorial
and formal review
H. Baden
2009-07-17 Add
Time sync frame to MUC-Status, separate ACC-No
U. Pahl
for wired M-Bus and wireless M-Bus
2.0.0
2.0.1
2009-07-20 Release
as V2.0.0
U. Pahl
U. Pahl
2010-04-10 Add
Changes for 3rd Version, Add sync Meter
transmission; New CI-Fields
2.0.2
2010-11-05 Add
Compact M-Bus Profile; Harmonise Spec. with
[prEN 13757-3]/[prEN 13757-4]
U. Pahl
2.0.3
2.0.4
3.0.0
3.0.1
4.0.0
2010-11-17 Revision
in AG1
AG1
2010-12-17 Comments
from members of AG1, Bug fix in Annex B
2011-01-21 Update
Changes from Standard revision
2011-01-28 Editorial
Revision. Release as V3.0.1
U. Pahl
U. Pahl
U. Pahl / A. Bolder
U.Pahl / A. Bolder
2013-01-10 New
Introduction; Add BSI-support (AFL; new
2013-05-06 Encryption
Mode 7 (dyn. AES) and Mode 13 (TLS);
2013-07-02 restructure
chapters "Supported Device Types" and
2013-08-19 "Application
protocols"; Revision of OBIS-List format;
2013-08-30 Add
new M-Bus Datapoint list, add new section Address
2013-09-24 handling;
Add mandatory support of ELL, Add Mode C
2013-10-20 support,
Remove obsolete Annex E,F and M; general
2013-10-21 editorial
revision, Add new ext. Annex B, E,F,O and int
2013-10-23 Annex
J; Change Annex A to ext. Annex A; expand
rules for ELL-Access number and TPL-Access number
Add Timing Diagram fragm. SND-UD
4.0.1
4.0.2
4.1.0
2014-01-18 Changes
according to Enquiry comments (see
OMS_KommentareVol2Issue4_sortiert2_bearbAG1.doc)
U.Pahl
U.Pahl
U.Pahl
2014-01-27 Add
Note to Annex G; Rename VIF-Type to VIB-Type
Version 4.0.2 is released
2016-02-10 Editorial
revisions like Decimal-comma;
Update Terms "serial number, manufacturing number,
DIN-Fabrication number;
New chapter 3.3 "Address handling by Adapters";
4.1: Rename Title "Twisted Pair Connection (M-Bus)";
4.2.3.2: Ed. Revision + del. Footnote c in Tab.9;
Tab.10: Ignore FCB in wireless M-Bus;
Tab.10+Tab.11+Tab.28: add NACK;
5.1+5.2.1+5.2.4 min. datagram length;
6.2.6 Msg. counter initialisation with 0;
7.2.2.1 FCB vs ACC-No;
7.2.3 clearing of bits âany application errorâ
;
Tab.22 Bit23 set to 0
b
;
7.2.4.3 Add explanation for bits C,B,A,S,R,H,N;
7.2.4.4 Add explanation for bits N;
7.2.4.4/7.2.4.5 Notes about ELL-usage for wireless M-
Bus only;
OMS GROUP
2/143
Open Metering System Specification Vol.2
â
Primary Communication
Issue 5.0.1 / 2023-12 (RELEASE)
Version Date
Comment
Editor
4.1.0
2016-03-07 4.2.2.4
sync. transmission of static messages
4.2.3.1 tRO_slow in C2-Mode
U.Pahl
(cont.)
7.2.3+Annex D Update applicable CI-Fields
8.2.6 new chapter "Descriptors"
Annex K - new annex "Descriptors"
8.6 reset of Appl. Errors
8.6 Appl. Errors unencrypted
9.1 Encryption of protocols and M-bus data points; Byte
order of keys
Tab28: Default value AT/ATO
9.4.4 techn.revision of message counter
9.4.7 ed.revision of Key-calc
Tab.G4 Bug fix in column "hex coded"
Tab.1 Add CI=54h,55h,66h,67h,68h Application Select
Protocol
2016-06-13 Editorial
Changes according to
"20160616_OMS_Table4Comments_OMSS410.docx"
Change term "dynamic key" to "ephemeral key"
Change term "static key" to "persistent key"
1.2 update of version history
3.1.3.2 case 1) ELLA check by other device
4.1, 5.2.1, 8.2.1, 9.2.1 5.2.3.1 Add new headline
"General"
Move 4.2.2 (without subclauses 4.2.2.1-4.2.2.4) to a
new sub section 4.3.2.5 "Minimum time delay"
Move headline 8.1.1. to 8.1 and replace old headline 8.1
"General Requirements"
5.2.4 and 8.5 add exception of clock service
6.2.3 FID for unfragmented messages
6.2.4; 6.2.7, 9.1; 9.3.1 merge 2 bit fields AT and ATO to
a 4 bit AT-field
Move AFL.ML from 6.2.5 to 6.2.8
Add new 6.2.5 AFL.KI
7.1 Rename combined Transport/Application layer to
Transport layer to follows new structure of [EN 13757-7]
and [EN 13757-3]
Moving parts of subclause 7.1 to new subclause "8.1
Overview"
7.2.1; 7.2.4; Annex D: split CF in CF + CFE
7.2.4.4 Tab.22 update reserved fields;
7.2.4.4 Tab.23 extend KeyID to 4 bit
7.2.4.6 Tab.26+Tab.27 Signed data message was
withdrawn, Reserved values were updated
Extend Annex B with Enc.-requirements
Annex C update M-Bus-Master requirements
2016-06-13 Update
Annex J
Annex L: Adding Headlines L.1-L.8
Annex L.4 review Example with NACK
Bug Fix Annex N
Change Term "Encryption Mode" by "Security Mode"
Add new Subclause "8.8 Security Management
Protocol" and add CI-Fields C3h-C5h in Tab.1
2016-06-23 Add
new subclause 9.4 KeyID
Replace Annex L.8 by inst. procedure w/o repeater
4.1.1
2016-09-16 3.1.3.2
new condition to apply ELLA
5.2.3 Tab11 new footnote d (SND-NKE)
U.Pahl
6.2.5 Revision AFL-KI
Annex G.2 Update exceptions
2016-10-21 9.1
update definition of persistent and ephemeral key
7.3 update Tab.29 add reference/optional TPL for NACK
OMS GROUP
3/143
Open Metering System Specification Vol.2
â
Primary Communication
Issue 5.0.1 / 2023-12 (RELEASE)
Version Date
Comment
Editor
4.1.2
2016-12-16 9.3.2
update according to comments from BSI
9.1 Tab.30: add Footnote b
U.Pahl
Annex F: update Introduction
Annex G: Rename title to "Conversion of a Load Profile
to single data points"
Version v4.1.2 was released!
4.2.0
2019-09-20 1.3
chapter added
2.2 Tab. 1: CI fields added and changed
3.1.4 reference updated
AG1, A. Reissinger
4.3.1 new note
4.3.2.3 new reference, addition of 60 s interval
4.3.3.1, Tab. 9 changed
4.3.4 changed
5.2.5 changed
6 complete chapter optimized for standard references
7.2.3 changed
8.1 bullet point added
8.2 complete chapter added
8.4.4 paragraph added
8.4.7 changed
8.4.8 complete chapter added
8.6 changed
8.9 chapter added
9 chapter content and structure completely revised
9.1 Tab. 33 updated, column authentication added, Tab.
34 and 35 changed
Annexes A, B, E, F, H, J, K changed
Annex L:
changed to âinformativeâ
, drawings updated
Annex M added
Standard references updated
Editorial revision
4.2.1
4.3.0
2019-11-23 Release
version
A. Reissinger
2019-12-17 2.3
Tab. 3 changed
AG4, A. Reissinger
4.2.1 chapter added for new Annex P
and
4.2.2 last sentence deleted
5.1 chapter changed for new Annex P, last sentence in
2020-01-06 first
paragraph deleted
9.2.2 Tab. 38 corrected
Annex C content deleted
4.3.1
2020-03-19 Annex
P page revised
AG4, A. Reissinger
AG1, A. Reissinger
and
2020-05-04 Tab.
15, 33, 34 and 36 changed
Fig. 15 changed
8.2.5 changed
8.8 changed
and
âmeter(s)/actuator(s)â replaced with âmeterâ in all
locations
2020-05-26 8.1
changed, tab. 25 added
to 8.4.5.1
new paragraph added
2020-05-29 Tab.
1 changed
9.3.2 chapter structure fixed
2020-06-29 1.2
changed
Tab. 2 and 3 changed
Tab. 39 changed
AG1, A. Reissinger
A. Reissinger
4.3.2
to
2020-07-09 Release
candidate
OMS GROUP
4/143
Open Metering System Specification Vol.2
â
Primary Communication
Issue 5.0.1 / 2023-12 (RELEASE)
Version Date
Comment
Editor
4.3.3
2020-09-24 8.4.4
changed
9.2.3 changed
AG1, A. Reissinger
9.4.2.1 changed
and
Annex L.5 updated
2020-09-29 3.2
changed
8.4.5.2 changed
and
U. Pahl, T. Banz
A. Reissinger
2020-10-02 Editorial
changes
and
2020-10-13 Integration
of several action items:
AG1, A. Reissinger
T. Banz
Introduction of Annex M changed
5.2.5 changed
and
2020-10-22 Editorial
changes
Release
A. Reissinger
4.4.0
4.4.1
2021-09-08 Table
13: headline corrected
1.1, 1.2 changed: introduction of sensors
Tables 2 and 4 changed: introduction of sensors
T. Banz, A. Reissinger
D. Matussek
R. MÃ¼ller
Annex C: reference to new external Annex C added
2021-09-15 Table
24 changed
A. Reissinger
A. Reissinger
and
2021-09-29 Editorial
changes
and
D. Matussek, A. Reissinger
2021-10-21 Release
candidate
A. Reissinger
4.4.2
2021-12-01 9.2.3
added
Table 23: Title and headline changed
Editorial changes
AG1, A. Reissinger
Release
OMS GROUP
5/143
Open Metering System Specification Vol.2
â
Primary Communication
Issue 5.0.1 / 2023-12 (RELEASE)
Version Date
4.5.0
Comment
Editor
2022-01-31 4.3.2.2,
4.3.2.3 and 4.3.2.4 changed
7.2.4.4 and 7.2.4.6 changed
7.2.4.7 added
AG1, A. Reissinger
8.4.4 changed
Table 39 changed
Figure 16 changed
2022-02-10 Headline
of clause 9.3.2.3 edited
2022-02-24 2.3
changed
Table 38: footnote added
2022-03-18 2,3
changed
4.3.2.4 changed
8.4.4 changed
Table 2 changed
Table 22 headline changed
Table 36 headline and note changed
2022-06-10 Copyright
remark added to front page
2022-07-05 Editorial
changes on front page
2022-07-25 Table
1 changed (network management)
Table 24 changed (network management)
Tables 37 and 39 changed (transport key)
9.2 changed (transport key)
9.3 changed (communication partner)
2022-07-29
Introduction of term âOMS
end-d
eviceâ
2022-08-02 8.10
changed
Table 38 added
Table 35 changed
2022-08-31
3.1.4 changed
Table 36 added
Table 39 changed
2022-09-14 3.1.2.2
changed
7.2.4 changed
7.2.4.5 added
9.3.2.1 changed
9.3.7 added
Table 40 changed
Table 41 changed
D,2, D.3 and D.4 changed
2022-10-08 Editorial
update of tables
1.2 changed
7.2.4.7 changed
2022-10-15
Term âkey materialâ replaced by âkeying materialâ
Term âmaster
-
keyâ replaced by âmaster keyâ
Term âtransport keyâ replaced by âcommunication
security key
Figures 16, 17, 18 changed
Figures in Annex L changed
Release candidate
4.5.1
2022-11-08 Integration
of review comments
AG1, Achim Reissinger
to
2022-11-14 Release
OMS GROUP
6/143
Open Metering System Specification Vol.2
â
Primary Communication
Issue 5.0.1 / 2023-12 (RELEASE)
Version Date
5.0.0
Comment
Editor
2023-03-28 Complete
document: radio modes S (S1, S2) and
T
(T1, T2) removed
AG1,
AG1 TF Sensors,
Achim Reissinger
to
1.2 changed
2.1 revised
2023-10-14 2.2
changed
3.1 changed
4.3 changed
4.3.2.3 added
4.3.2.5 deleted
4.3.3.2 deleted (including table 10)
7.2.4.5 note added
8.4.5.1 changed
8.7 changed
9.1 changed
Figure 8 added
Figure 11 updated
Figure 13 changed
Figure 9 deleted
Table 2 changed for device types 00h, 18h, 1Ah, 1Dh,
1Eh, 1Fh and footnotes
Table 41 changed
Annex C removed
Annex G changed: G.3 and G.7 added
Annex J changed: figure revised
Annex L changed: figures revised
Annex Q added
Annex R added
Release candidate
5.0.1
2023-11-14 Consideration
of review comments
AG1, Achim Reissinger
to
2024-02-08 Release
OMS GROUP
7/143
Open Metering System Specification Vol.2
â
Primary Communication
Issue 5.0.1 / 2023-12 (RELEASE)
Contents
Document History...................................................................................................................2
Contents.................................................................................................................................8
Tables ..................................................................................................................................13
Figure
s
.
................................................................................................................................15
1
Introduction .................................................................................................................17
1.1 General
.......................................................................................................................17
1.2 Version
History............................................................................................................17
1.3 Reference
...................................................................................................................18
2
M-Bus Frame Structur
e
.
..............................................................................................19
2.1 OMS-Layer
Model .......................................................................................................19
2.1.1 Overvie
w
.
...........................................................................................................19
2.1.2 Mode
C specificatio
n
.
.........................................................................................20
2.1.3
âOMS LPWAN â Burst Modeâ specification
........................................................21
2.1.4
âOMS LPWAN â Splitting Modeâ specification
....................................................22
2.1.5 Wired
M-Bus specificatio
n
.
.................................................................................23
2.2 Supported
CI-Fields ....................................................................................................23
2.3 Supported
Device Type
s
.
............................................................................................26
3
Address Handling........................................................................................................29
3.1 M-Bus
Address............................................................................................................29
3.1.1 Overvie
w
.
...........................................................................................................29
3.1.2 Wired
M-Bus ......................................................................................................29
3.1.3 Wireless
M-Bus (Frame Format A
)
.
....................................................................30
3.1.4 Wireless
M-Bus (Frame Format C).....................................................................33
3.1.5 M-Bus
Address Element
s
.
..................................................................................35
3.2 DIN
Address................................................................................................................36
3.3 Address
Handling by Adapter
s
.
...................................................................................37
4
Physical Layer .............................................................................................................39
4.1 General
.......................................................................................................................39
4.2 Wired
Communication (Wired M-Bus) .........................................................................39
4.2.1 Genera
l
.
.............................................................................................................39
4.2.2 Electrical
Specification .......................................................................................39
4.2.3 Hardware
Connections and Wirin
g
.
....................................................................39
4.3 Wireless
Communication (Wireless M-Bus).................................................................39
4.3.1 Modes
and Requirements ..................................................................................39
4.3.2 Wireless
Data Transmission Intervals ................................................................41
4.3.3 Access
Timing of a Bidirectional OMS end-device .............................................44
4.3.4 Transmissions
Limits and Transmission Credits.................................................47
OMS GROUP
8/143
Open Metering System Specification Vol.2
â
Primary Communication
Issue 5.0.1 / 2023-12 (RELEASE)
5
Link Layer ....................................................................................................................49
5.1 Wired
Communication (Wired M-Bus) .........................................................................49
5.2 Wireless
Communication (Wireless M-Bus).................................................................49
5.2.1 Genera
l
.
.............................................................................................................49
5.2.2 Frame
Format
A
.
................................................................................................49
5.2.3 Frame
Format C.................................................................................................51
5.2.4 Supported
C-Fields ............................................................................................52
5.2.5 Repeater
for the Wireless Communication .........................................................54
5.2.6 Rules
for the Gateway........................................................................................55
6
Authentication and Fragmentation Layer ..................................................................56
6.1 General
.......................................................................................................................56
6.2 Rules
for Specific AFL Fields ......................................................................................56
6.2.1 AT-Subfield
of AFL.MCL ....................................................................................56
6.2.2 AFL.K
I
.
...............................................................................................................56
6.2.3 AFL.MCR
...........................................................................................................56
6.2.4 AFL.MAC
...........................................................................................................56
6.2.5 AFL.ML
..............................................................................................................56
6.3 Conditions
to Apply an AF
L
.
........................................................................................57
7
Transport Layer ...........................................................................................................58
7.1 Overvie
w
.
....................................................................................................................58
7.2 Common
Part for All Transport Layers ........................................................................58
7.2.1 General
Structure of the Transport Layer ...........................................................58
7.2.2 Access
Number..................................................................................................59
7.2.3 Status
Byte.........................................................................................................60
7.2.4 Configuration
Fiel
d
.
............................................................................................61
7.3 Conditions
to Apply the Transport Layer......................................................................67
8
Application Protocols..................................................................................................69
8.1 Overvie
w
.
....................................................................................................................69
8.2 Message
Types and Their Application Data Conten
t
.
..................................................69
8.2.1 Overvie
w
.
...........................................................................................................69
8.2.2 SND-IR...............................................................................................................70
8.2.3 SND-NR/ACC-NR
..............................................................................................70
8.2.4 RSP-UD/ACK
after REQ-UD
1
.
...........................................................................71
8.2.5 RSP-UD
after REQ-UD2 or SND-UD2................................................................72
8.3 Resolution
and Accuracy of Consumption Data...........................................................74
8.4 M-Bus
Application Protocol .........................................................................................74
8.4.1 Genera
l
.
.............................................................................................................74
8.4.2 OMS-Data
Point List...........................................................................................74
8.4.3 OMS-Gateway....................................................................................................74
8.4.4 OMS
end-device ................................................................................................75
OMS GROUP
9/143
Open Metering System Specification Vol.2
â
Primary Communication
Issue 5.0.1 / 2023-12 (RELEASE)
8.4.5 Usage
of Specific Data Point
s
.
...........................................................................76
8.4.6 OBIS
Code.........................................................................................................77
8.4.7 Descriptors.........................................................................................................77
8.4.8 Commands.........................................................................................................77
8.5 DLMS
Application Protocol..........................................................................................78
8.6 SML
Application Protocol ............................................................................................78
8.7 Clock
Synchronisation Protoco
l
.
..................................................................................78
8.8 Application
Error Protocol............................................................................................78
8.9 Security
Management Protocol....................................................................................79
8.10 Application
Select Protocol..........................................................................................79
9
Securit
y
.
.......................................................................................................................81
9.1 General
.......................................................................................................................81
9.2 Key
Managemen
t
.
.......................................................................................................84
9.2.1 Genera
l
.
.............................................................................................................84
9.2.2 KeyI
D
.
................................................................................................................84
9.2.3 Key
Generation ..................................................................................................86
9.2.4 Key
Exchang
e
.
...................................................................................................86
9.2.5 Key
Derivation Function .....................................................................................87
9.3 Communication
security ..............................................................................................89
9.3.1 Genera
l
.
.............................................................................................................89
9.3.2 Message
counter................................................................................................89
9.3.3 MAC-Generation
................................................................................................93
9.3.4 No
Encryption with Security Mode 0...................................................................93
9.3.5 Symmetric
Encryption with Security Mode 5.......................................................93
9.3.6 Symmetric
Encryption with Security Mode 7.......................................................93
9.3.7 Symmetric
Authenticated-Encryption with Security Mode 1
0
.
.............................94
9.3.8 Asymmetric
Encryption with Security Mode 1
3
.
..................................................94
9.4 Application
security .....................................................................................................94
9.4.1 Genera
l
.
.............................................................................................................94
9.4.2 Application
security profile..................................................................................96
Anne
x
.
.................................................................................................................................98
Annex A (Normative): List of OBIS Codes for OMS end-device
s
.
.........................................98
Annex B (Normative): OMS-Data Point Lis
t
.
.........................................................................99
Annex C (Empty
)
.
...............................................................................................................100
Annex D (Informative): The Structure of the Transport and Application Layer ....................101
D.1
D.2
D.3
D.4
No TPL-header.................................................................................................101
Short TPL-header.............................................................................................101
Long TPL-header .............................................................................................102
Legen
d
.
............................................................................................................102
Annex E (Normative): Communication profiles for compliance with national regulations.....103
OMS GROUP
10/143
Open Metering System Specification Vol.2
â
Primary Communication
Issue 5.0.1 / 2023-12 (RELEASE)
E.1
E.2
Requirements for Smart Meter Gateways in Germany .....................................103
Requirements for Compliance with IDIS Association in Europ
e
.
.......................103
Annex F (Normative): Transport Layer Security (TLS) with Wireless M-Bu
s
.
......................104
Annex G (Normative): Conversion of a Load Profile to Single Data Points .........................105
G.1
G.2
G.3
G.4
G.5
G.6
G.7
Treatment of Historical Values in Compact Load Profiles with Register
s
.
.........105
Applicable Standar
d
.
........................................................................................105
Applicable Storage numbers ............................................................................105
Data Set of the Example ..................................................................................105
Example for Standard Load Profile...................................................................106
Example for Compact Load Profil
e
.
..................................................................107
Example for an Inverse Compact Load Profile..................................................108
Annex H (Informative): Gas Meter Consumption Data and Their Codin
g
.
...........................109
H.1
H.2
H.3
H.4
H.5
H.6
Glossary...........................................................................................................109
Overvie
w
.
.........................................................................................................109
Volume at Measurement Conditions.................................................................110
Temperature Converted Volume V
tc
.................................................................110
Temperature and Pressure Converted Volume ................................................111
OBIS / COSEM Application of Physical Units for Gas.......................................112
Annex I (Normative): Collision Avoiding Mechanism of the Gatewa
y
.
.................................113
I.1
I.2
I.3
I.4
I.5
Flowchart .........................................................................................................114
Explanation ......................................................................................................115
Example: Access of One Gateway without Collision.........................................115
Example: Access of Two Gateways with Collisio
n
.
...........................................116
Collision Probabilities .......................................................................................118
Annex J (Informative): Handling of Message Counter.........................................................119
Annex K (Normative): Descriptors ......................................................................................123
K.1
K.2
K.3
K.4
K.5
Genera
l
.
...........................................................................................................123
Storage Descriptors..........................................................................................123
Subunit Descriptor............................................................................................125
Tariff Descriptor................................................................................................126
Examples .........................................................................................................127
Annex L (Informative): Timing Diagram ..............................................................................129
L.1
L.2
Legen
d
.
............................................................................................................129
Unidirectional OMS end-device with Synchronous and Asynchronous
Transmission....................................................................................................130
L.3
L.4
L.5
L.6
L.7
L.8
L.9
RF-Connection with SND-UD and Short TPL ...................................................131
Transmission of Fragmented Message with SND-UD.......................................132
Transmission of ACK + RSP-UD with Different Command States ....................133
RF-Connection with SND-UD2 and Long TP
L
.
.................................................134
Connection Timeout of the Frequent Access Cycle ..........................................135
Access Demand from OMS end-device............................................................136
Installation Procedure.......................................................................................137
Annex M (Normative): Requirements for OMS Use Case Support......................................138
OMS GROUP
11/143
Open Metering System Specification Vol.2
â
Primary Communication
Issue 5.0.1 / 2023-12 (RELEASE)
Annex N (Informative): Datagram Examples for Wired M-Bus and Wireless M-Bus............139
Annex O (Informative): Alternative Physical Layers for OM
S
.
.............................................140
Annex P (Normative and Informative): Requirements for Wired M-Bus ..............................141
Annex Q (Normative): OMS LPWAN ..................................................................................142
Annex R (Normative): Meter Reading Transmission via M-Bus Compact Profile; to meet BSI
TR-03109-1 TAF7 .....................................................................................................143
OMS GROUP
12/143
Open Metering System Specification Vol.2
â
Primary Communication
Issue 5.0.1 / 2023-12 (RELEASE)
Tables
Table 1
â
List of supported CI-Field
s
.
...................................................................................23
Table 2
â
Device Types of OMS end-device (certifiable with OMS-CT
)
.
...............................27
Table 3
â
Device Types of other OMS end-devices (prepared for OMS-CT) ........................27
Table 4
â
Device Types of not certifiable device...................................................................28
Table 5
â
Location of the OMS end-device address .............................................................35
Table 6
â
Structure of the DIN Addres
s
.
...............................................................................36
Table 7
â
Default Device Type in case of DIN-Address conversio
n
.
.....................................37
Table 8
â
Update interval of consumption data for billing......................................................42
Table 9
â
Update interval of Sensor data for different devices..............................................43
Table 10
â
Accessibility of an OMS end-devic
e
.
...................................................................45
Table 11
â
Credits per datagra
m
.
.........................................................................................47
Table 12
â
Maximum access opportunity dela
y
.
...................................................................48
Table 13
â
Minimum credits per radio mode.........................................................................48
Table 14
â
Definition of the Communication Control Field (CC)............................................51
Table 15
â
C-Fields of master (gateway or other communication device
)
.
............................52
Table 16
â
C-Fields of slave (OMS end-device) ...................................................................52
Table 17
â
Application error bits in OMS end-device status byt
e
.
.........................................60
Table 18
â
General definition of the Configuration Field .......................................................61
Table 19
â
Definition of the Configuration Field for security mode MMMMM = 5 ..................62
Table 20
â
Configuration Field for security mode 7...............................................................63
Table 21
â
Configuration Field Extension for security mode
7
.
.............................................63
Table 22
â
Configuration Field for security mode 10.............................................................64
Table 23
â
Configuration Field Extension for security mode 10 ............................................64
Table 24
â
Configuration Field for security mode 13.............................................................65
Table 25
â
Configuration Field Extension for security mode 13 ............................................66
Table 26
â
OMS usage of Content Index bits for CC = 00
b
.
.................................................66
Table 27
â
OMS usage of Content Index bits for CC = 01b ..................................................66
Table 28
â
Usage of TPL depending on message type ........................................................68
Table 29
â
Application protocols...........................................................................................69
Table 30
â
Message types and their application data content...............................................70
Table 31
â
States of a SND-IR .............................................................................................70
Table 32
â
State change events of a SND-I
R
.
......................................................................70
Table 33
â
States of a SND-NR/ACC-N
R
.
............................................................................71
Table 34
â
State change events of a SND-NR/ACC-NR.......................................................71
Table 35
â
States of a RSP-UD/ACK after REQ-UD1...........................................................72
Table 36
â
State change events of a RSP-UD after REQ-UD1.............................................72
5
10
15
20
25
30
35
OMS GROUP
13/143
Open Metering System Specification Vol.2
â
Primary Communication
Issue 5.0.1 / 2023-12 (RELEASE)
Table 37
â
States of a RSP-UD after REQ-UD2/SND-UD2 ..................................................73
Table 38
â
State change events of a RSP-UD after REQ-UD2/SND-UD
2
.
...........................74
Table 39
â
Conditions for obligatory/conditional data points in SND-NR messages..............75
Table 40
â
OMS Application error code
s
.
.............................................................................79
Table 41
â
List of message application
s
...............................................................................80
Table 42
â
Encryption and authentication of application protocols........................................81
Table 43
â
OMS Security profile
s
.
........................................................................................83
Table 44
â
Required Security profiles...................................................................................84
Table 45
â
Predefined OMS-KeyIDs.....................................................................................84
Table 46
â
Constant (DC) for the key derivatio
n
.
..................................................................88
Table 47
â
OMS Application security profiles .......................................................................96
Table G.1
â
Example: Load profile of consumption values for a water meter......................105
Table G.2
â
Example: Standard Load Profile composed of the periodical volume value
s
.
..106
Table G.3
â
Example: Periodical volume values converted to single data point
s
.
...............106
Table G.4
â
Example: Compact Load Profile composed of the periodical volume values ...107
Table G.5
â
Example: Periodical volume values converted to single data point
s
.
...............107
5
10
15
Table G.6
â
Example: Inverse Compact Load Profile composed of the periodical volume
values ................................................................................................................108
Table G.7
â
Example: Periodical volume values converted to single data point
s
.
...............108
Table H.1
â
Glossary of the Gas meter consumption data..................................................109
Table H.2
â
Enumerated values for physical unit
s
.
.............................................................112
Table H.3
â
Examples for scaler-unit..................................................................................112
Table K.1
â
Overview of descriptors and related DIB-element
s
.
.........................................123
Table K.2
â
Declaration of Storage interval descriptors ......................................................124
Table K.3
â
Declaration of Storage range descriptors ........................................................124
Table K.4
â
Subunit index values for the subunit descriptor ...............................................125
Table K.5
â
Tariff index values for the tariff descripto
r
.
.......................................................126
Table K.6
â
Example load profile for storage descriptor......................................................127
Table K.7
â
Example for coding of the storage descriptor...................................................128
20
25
30
OMS GROUP
14/143
Open Metering System Specification Vol.2
â
Primary Communication
Issue 5.0.1 / 2023-12 (RELEASE)
Figures
Figure 1
â
OMS Layer model................................................................................................19
Figure 2
â Layers included in the âOMS Mode Câ specification.
............................................20
Figure 3
â Layers included in the âOMS LPWAN â Burst Modeâ specification.
.....................21
Figure 4
â Layers included in the âOMS LPWAN â Splitting Modeâ specification.
.................22
Figure 5
â
Layers included in the wired M-Bus specification.................................................23
Figure 6
â
Primary Address for wired M-Bus (Example) .......................................................29
Figure 7
â
Secondary Addresses for wired M-Bus (Example)...............................................30
Figure 8
â
Addresses for wireless M-Bus (without ELLA) .....................................................31
Figure 9
â
Addresses for wireless M-Bus (with ELLA
)
.
.........................................................32
Figure 10
â
Addresses for wired and wireless M-Bus (with ELLA, example).........................32
Figure 11
â
Detection of the ALA..........................................................................................33
Figure 12
â
Address usage in FFC for an allocated gateway................................................34
Figure 13
â
Address usage in FFC for a not allocated gateway............................................34
Figure 14
â
Address usage in FFC with RF-Adapter ............................................................34
Figure 15
â
Address handling of an RF or M-Bus adapte
r
.
...................................................38
Figure 16
â
Access number for synchronous and asynchronous transmissions ...................41
5
10
15
Figure 17
â
Access timing of an OMS end-device with short access windows (Mode C2
example
)
.
.............................................................................................................46
20
Figure 18
â
Short ELL without receiver addres
s
.
..................................................................50
Figure 19
â
Long ELL with receiver address.........................................................................50
Figure 20
â
Access Numbe
r
.
................................................................................................59
Figure 21
â
States of an externally triggered transmission even
t
..........................................70
Figure 22
â
States of a periodical transmission event...........................................................71
Figure 23
â
Alarm response state
s
.
......................................................................................71
Figure 24
â
Data response states.........................................................................................73
Figure 25
â
Keys used for the key exchange of symmetrical keys
.
.
......................................87
Figure 26
â
Handing of the message counter in the OMS end-device ..................................90
Figure 27
â
Handing of the message counter in the communication partner.........................92
Figure 28
â
Application security versus Communication security..........................................95
Figure H.1
â
Gas meter providing volume at measurement condition
s
.
..............................110
Figure H.2
â
Gas meter providing temperature converted volum
e
.
.....................................110
Figure H.3
â
Gas meter providing temperature and pressure converted volume ................111
Figure I.1 - Collision avoiding algorithm..............................................................................114
Figure I.2
â
Timing diagram without collisions ....................................................................116
Figure I.3
â
Timing diagram with collisions .........................................................................117
Figure I.4
â
Collision probability..........................................................................................118
25
30
35
OMS GROUP
15/143
Open Metering System Specification Vol.2
â
Primary Communication
Issue 5.0.1 / 2023-12 (RELEASE)
Figure J.1
â
Example of message counter handling ...........................................................122
OMS GROUP
16/143
Open Metering System Specification Vol.2
â
Primary Communication
Issue 5.0.1 / 2023-12 (RELEASE)
1
Introduction
1.1 General
This part describes the minimum Open Metering System requirements for the wired and the
wireless communication between a slave (OMS end-device) and the (stationary, usually mains
powered) master (gateway or other communication unit). It covers the Physical Layer, the Link
Layer, the general requirements for communication security (covered in the Authentication and
Fragmentation Layer and in the Transport Layer) and the application itself. The Application
Layer is focused on the M-Bus protocol. But it also supports the DLMS/COSEM protocol and
an SML-based protocol. Detailed information about the required values and the time resolution
are given.
5
10
This part concentrates on the requirements for OMS end-devices. This specification supports
both mains powered devices (e.g. electricity meters or actuators) and battery driven devices
(e.g. water meters, gas meters or thermal energy meters or sensors related to metering).
The total system overview is provided in Volume 1 [OMS-S1] of the Open Metering System
specificatio
n.
1
15
An overall glossary with definitions and abbreviations is provided as a separate Annex of
Volume 1 [OMS-S1] of the Open Metering System Specification (general part).
The referenced standards and documents (marked with square brackets (e.g.
[EN 13757-3:2018]) are listed in the Open Metering System Specification (general part).
20
25
Note that according to the use of verbal forms for the expression of provisions in standards
statements with a âshallâ describe mandatory requirements. Statements with a âshouldâ
describe recommendations.
Hexadecimal numbers are marked with a suffix "h". Binary coded numbers are marked with a
suffix "b". Numbers without suffix are decimal numbers except where another coding is
explicitly declared.
1.2 Version History
Issue 1.0 is the very first release with limitation to unidirectional meters only.
Issue 2.0 amends regulation of the standard to access bidirectional meters or actuators. The
use of repeaters was substantiated. Parts were adapted to ensure coexistence with NTA 8130.
30
35
40
Issue 3.0 introduces the synchronous transmission timing to support the long-term use of
battery powered bidirectional repeaters. Some new CI-Fields were adopted to support the
consequent use of Short and Long TPL-headers for wireless datagrams.
Issue 4.0 extends the applicable security methods. It allows compliance with the requirements
of the German Federal Office for Information Security (Bundesamt fÃ¼r Sicherheit in der
Informationstechnik
â
BSI) when using
Annex E.
It applies an update according to the release
of [EN 13757-3:2013] and [EN 13757-4:2013].
Issue 4.1 is an improvement of issue 4.0. Besides a lot of minor changes, it contains an
extension of Application select protocol, a new
Annex K
with data point descriptors, updated
Annexes A and B containing encryption requirements for each data point, improved description
of message counter handling, static messages, and address handling of a radio adapter.
1
This document shall only be applied in combination with [OMS-S1] Issue 2.0.0 or higher!
OMS GROUP
17/143
Open Metering System Specification Vol.2
â
Primary Communication
Issue 5.0.1 / 2023-12 (RELEASE)
Issue 4.2 is an improvement of issue 4.1. Besides many minor changes, reference updates
and updated annexes it provides an updated credit counter mechanism, a detailed status byte
handling and a definition of application errors. Especially for the upcoming 2-way use cases of
Annex M
it introduces the application layer security and it defines the applicative behaviour of
an OMS end-device especially for bidirectional communications. This version introduces
Annex F
to support security profile C.
5
Issue 4.3 is an improvement of issue 4.2. It introduces two new annexes:
Annex M
for
additional optional bidirectional use cases and
Annex P
for the Wired M-Bus. Consequently,
Annex C was removed as the master requirements are included in
Annex P.
The Annexes B,
E and N were revised as a result of the introduction of
Annex M.
Annex B
contains in its revision
commands.
Annex E
supports in its revision IDIS meters. In chapter 8.2.5 the behaviour in
case of an error was revised. Further changes are listed in the document history.
10
Issue 4.4 integrates the communication of sensors related to metering and their device types
in the new Annex C. The sensor related data points have been added to
Annex B.
15
20
Issue 4.5 introduces the new term âOMS end
-
deviceâ
, which covers meters, sensors and
actuators, introduces harmonised content index values (see
8.4.4)
, harmonises the message
application (see
8.10)
, introduces a new Security profile D (see
9.3.7)
, applies a new concept
for command action codes in
Annex B,
creates new use cases i
n Annex M
and provides a
correction in
Annex P.
Additional changes are listed in the document history.
Issue 5.0 introduces the new
Annex Q
defining OMS LPWAN, creates new use cases in
Annex
M,
removes the definitions for the radio modes S and T and implements changes for the coding
of sensors according to prEN 13757-3/-7:2023, thus removing Annex C. Additional changes
are listed in the document history.
1.3 Reference
25
References to other documents are marked with square brackets. They are defined in Volume
1 [OMS-S1].
OMS GROUP
18/143
Open Metering System Specification Vol.2
â
Primary Communication
Issue 5.0.1 / 2023-12 (RELEASE)
2
M-Bus Frame Structure
2.1 OMS-Layer Model
2.1.1 Overview
The M-Bus Protocol is separated in several layers based on the OSI 7 Layer Model. This
document is structured according to the applied communication layers shown in
Figure 1.
5
APL
Application Layer
TPL
Transport Layer
AFL
Authentication and Fragmentation Layer
ELL
LLC
Extended Link Layer
DLL
Data Link
Layer
Logical Link Control Layer
EN 13757-4
DLL
Data Link Layer
EN 13757-4
MAC
EN 13757-2
Medium Acces Control Layer
PHY
PHY
PHY
PHY
Wireless M-Bus Mode C
EN 13757-4
OMS LPWAN
Burst Mode
OMS LPWAN
Splitting Mode
Wired M-Bus
EN 13757-2
Figure 1
â
OMS Layer model
The Physical Layer and the Data Link Layer are always present for Mode C and wired M-Bus.
OMS LPWAN (see
Annex Q)
introduces a new Link Layer containing the Medium Access
Control Layer (MAC) and the Logical Link Control Layer (LLC). These layers are mandatory
for OMS LPWAN with the exception of pure MAC layer frames that does not contain any higher
layers. The MAC and LLC are not introduced by a CI-field.
10
15
The Transport Layer and the applied Application Layer (if existent) are always introduced by
the Transport Layerâs CI
-Field. Optional layer
s
3
like ELL or AFL are introduced by special CI-
Fields. In such a case the M-Bus-message contains several CI-Fields, chained to one another.
The OMS Layer Model can be realised in an OMS end-device according to one or more OMS
modes from the following sub clauses.
3
[EN 13757-5] supports an additional network layer located between ELL and AFL. This layer is never
used in the Open Metering System.
OMS GROUP
19/143
Open Metering System Specification Vol.2
â
Primary Communication
Issue 5.0.1 / 2023-12 (RELEASE)
2.1.2 Mode C specification
An OMS end-device according to this specification includes the layers shown in
Figure 2.
APL
Application Layer
TPL
Transport Layer
AFL
Authentication and Fragmentation Layer
ELL
Extended Link Layer
EN 13757-4
DLL
Data Link Layer
EN 13757-4
PHY
Wireless M-Bus Mode C
EN 13757-4
Figure 2
â Layers included in the âOMS Mode Câ specification.
The PHY, DLL and ELL shall be according to [EN 13757-4].
5
Further requirements for this implementation are defined in this specification.
OMS GROUP
20/143
Open Metering System Specification Vol.2
â
Primary Communication
Issue 5.0.1 / 2023-12 (RELEASE)
2.1.3
âOMS LPWAN â Burst Modeâ specification
An OMS end-device according to this specification includes the layers shown in
Figure 3.
APL
Application Layer
TPL
Transport Layer
AFL
Authentication and Fragmentation Layer
LLC
Logical Link Control Layer
MAC
Medium Acces Control Layer
PHY
OMS LPWAN
Burst Mode
Figure 3
â Layers included in the âOMS LPWAN â Burst Modeâ specification.
The PHY, MAC and LLC shall be according to
Annex Q.
5
Further requirements for this implementation are defined in this specification.
OMS GROUP
21/143
Open Metering System Specification Vol.2
â
Primary Communication
Issue 5.0.1 / 2023-12 (RELEASE)
2.1.4
âOMS LPWAN â Splitting Modeâ specification
An OMS end-device according to this specification includes the layers shown in
Figure 4.
APL
Application Layer
TPL
Transport Layer
AFL
Authentication and Fragmentation Layer
LLC
Logical Link Control Layer
MAC
Medium Acces Control Layer
PHY
OMS LPWAN
Splitting Mode
Figure 4
â Layers included in the âOMS LPWAN â Splitting Modeâ specification.
The PHY, MAC and LLC shall be according to
Annex Q.
5
Further requirements for this implementation are defined in this specification.
OMS GROUP
22/143
Open Metering System Specification Vol.2
â
Primary Communication
Issue 5.0.1 / 2023-12 (RELEASE)
2.1.5 Wired M-Bus specification
APL
Application Layer
TPL
Transport Layer
AFL
Authentication and Fragmentation Layer
DLL
Data Link
Layer
EN 13757-2
PHY
Wired M-Bus
EN 13757-2
Figure 5
â
Layers included in the wired M-Bus specification.
The requirements for the implementation of wired M-Bus are defined in this specification and
especially i
n Annex P.
5
2.2 Supported CI-Fields
The CI-Field declares the communication layer, the transport direction (not applicable for lower
layers like ELL and AFL), and the Application Protocol (if existent). The CI-Field also declares
the applied type of Transport Layer header ("None", "Short" or "Long", see [EN 13757-7:2018],
7.2 to 7.5 for details).
10
Downlink messages are received by the OMS end-device and uplink messages are transmitted
by the OMS end-device.
The following CI-Fields are allowed for OMS-Communication:
15
Table 1
â
List of supported CI-Fields
Up- or
Down-
link
TPL-
header-
Type
CI-Field Function/Layer
Protocol or Service
Application Reset or
50h
d, f
Select
Down
None
Application Select
51h
d, f
52h
d, f
Command
Down
Down
None
None
M-Bus
M-Bus
Selection of Device
OMS GROUP
23/143
Open Metering System Specification Vol.2
â
Primary Communication
Issue 5.0.1 / 2023-12 (RELEASE)
Up- or
Down-
link
TPL-
header-
Type
CI-Field Function/Layer
Protocol or Service
Application Reset or
Select
53h
Down
Down
Down
Down
Down
Long
None
Long
Short
Short
Application Select
Application Select
Application Select
Application Select
Application Select
Request of selected
application
54h
d, f
Request of selected
application
55h
Request of selected
application
56h
d, e
Application Reset or
57h
d, e
Select
5Ah
d, e
Command
Command
Down
Down
Short
Long
M-Bus
M-Bus
5Bh
Security Management (TLS-Handshake)
(see
Annex F)
5Fh
Command
Down
Long
60h
Command
Command
Time Sync
Command
Command
Down
Down
Down
Down
Down
Long
Short
Short
Long
Short
DLMS
b
61h
d, e
62h
d, e
64h
DLMS
b
Clock Synchronisation
SML
b
65h
d, e
SML
b
Response of selected
application
66h
d
67h
Up
Up
Up
None
Short
Long
Application Select
Application Select
Application Select
Response of selected
application
Response of selected
application
68h
6Ch
6Dh
6Eh
6Fh
70h
d, f
71h
d, f
72h
Time Sync
Time Sync
Application Error
Application Error
Application Error
Alarm
Down
Down
Up
Long
Long
Short
Long
None
None
Long
Short
Long
Short
Long
Short
Long
Short
Long
Clock Synchronisation
Clock Synchronisation
Application Error
Application Error
Application Error
Alarm
Up
Up
Up
Response
Up
M-Bus
74h
Alarm
Up
Alarm
75h
Alarm
Up
Alarm
7Ah
7Ch
7Dh
7Eh
7Fh
80h
Response
Up
Wireless M-Bus
DLMS
b
Response
Up
Response
Up
DLMS
b
Response
Up
SML
b
Response
Up
SML
b
Pure Transport Layer
Down
None
Network management Protocol (see
[EN 13757-4:2019] clause 14)
82h
e
Network management
Down
Long
OMS GROUP
24/143
Open Metering System Specification Vol.2
â
Primary Communication
Issue 5.0.1 / 2023-12 (RELEASE)
Up- or
Down-
link
TPL-
header-
Type
CI-Field Function/Layer
Protocol or Service
Network management Protocol (see
[EN 13757-4:2019] clause 14)
87h
e
88h
e
Network management
Up
Up
Long
Short
Network management Protocol (see
[EN 13757-4:2019] clause 14)
Network management
8Ah
Pure Transport Layer
Pure Transport Layer
Extended Link Layer
Extended Link Layer
Up
Up
Short
Long
None
8Bh
None
8Ch
c, e
8Eh
c, e
Up/Down N/A
Up/Down N/A
Lower Layer Service (2 Byte)
Lower Layer Service (10 Byte)
Authentication and
Fragmentation Layer
90h
c
Up/Down N/A
Lower Layer Service
Network management Protocol (see
[EN 13757-4:2019] clause 14)
92h
d, e
93h
d, e
9Eh
Network management
Pure Transport Layer
Response
Down
Down
Up
Short
Short
Short
None
Security Management (TLS-Handshake)
(see
Annex F)
Security Management (TLS-Handshake)
(see
Annex F)
9Fh
Response
Up
Long
None
None
None
None
None
Set baud rate to
300 baud
B8h
d, f
BBh
d, f
BDh
d, f
BEh
d, f
BFh
d, f
Down
Down
Down
Down
Down
Link Layer Control
Link Layer Control
Link Layer Control
Link Layer Control
Link Layer Control
Set baud rate to
2400 baud
Set baud rate to
9600 baud
Set baud rate to
19200 baud
Set baud rate to
38400 baud
C0h
Command
Response
Response
Command
Response
Response
Command
Command
Down
Up
Long
Short
Long
Long
Short
Long
Short
Short
Image transfer (see
Annex M.2)
Image transfer (see
Annex M.2)
Image transfer (see
Annex M.2)
Security Information Transport
Security Information Transport
Security Information Transport
Security Information Transport
Image transfer (see
Annex M.2)
MBAL acc. to prEN13757-8
C1h
C2h
Up
C3h
Down
Up
C4h
C5h
Up
C6h
d, e
C7h
d, e
Down
Down
CFh
c, d, e, f
M-Bus Adaptation Layer
Up/Down N/A
a
Footnote is obsolete and has been deleted.
b
Refer also [EN 13757-1:2014], [EN 62056-6-1:2013], [DLMS UA] or [SML-spec]
These CI-Fields are used for lower layers and may be used in combination with another CI-Field
These CI-Fields shall not be used for wireless M-Bus Mode C.
These CI-Fields shall not be used for wired M-Bus.
These CI-Fields shall not be used with OMS LPWAN.
c
d
e
f
N/A
Not applicable
OMS GROUP
25/143
Open Metering System Specification Vol.2
â
Primary Communication
Issue 5.0.1 / 2023-12 (RELEASE)
2.3 Supported Device Types
This specification covers only devices with a Device Type listed in
Table 2
or
Table 3.
NOTE:
The Device Types listed in
Table 4
may also be integrated in the Open Metering
System, but cannot be approved by the OMS-Compliance Test. Therefore, interoperability for
these Devices Types is not guaranteed.
5
OMS-Gateways shall accept all the Device Types listed in
Table 2
and
Table 3
(except device
types 25h, 31h and 36h). Optionally they may also support Device types listed in
Table 4.
For further details on Device Types refer to [EN 13757-7:2018], 7.5.4, Table 13
â
Device type
identification.
10
Columns labelled
âcategoryâ
list the mapping from Device Type to corresponding OBIS-
category / energy type as specified in subclause
3.2
of [DIN 43863-5:2012]
(âIdentification
number for measuring devices applying for all manufacturersâ)
.
OMS GROUP
26/143
Open Metering System Specification Vol.2
â
Primary Communication
Issue 5.0.1 / 2023-12 (RELEASE)
Table 2
â
Device Types of OMS end-device (certifiable with OMS-CT)
Device Type
Code
00h
02h
03h
04h
06h
07h
08h
0Ah
0Bh
0Ch
0Dh
15h
16h
18h
1Ah
1Dh
1Eh
1Fh
28h
20h
21h
Category
Other
F
1
7
6
9
8
4
5
5
6
6
9
8
F
F
F
F
F
F
F
F
Electricity meter
Gas meter
Heat meter
Warm water meter (30Â°C ... 90Â°C)
Water meter
Heat Cost Allocator
Cooling meter (Volume measured at return temperature: outlet)
Cooling meter (Volume measured at flow temperature: inlet)
Heat meter (Volume measured at flow temperature: inlet)
Combined Heat / Cooling meter
Hot water meter (â¥
90Â°C)
Cold water meter
a
Pressure device
c
Smoke alarm device
d
Carbon monoxide alarm device
d
Heat alarm device
d
Sensor device
e
Waste water meter
Breaker (electricity)
b
Valve (gas or water)
b
a
Device Type 16h is to be used for cold drinking water that temporarily has been cooled
or heated in order to achieve the wanted temperature (chilling/antifreeze).
Annex M, O
MS-UC-03 shall be applied for OMS conformance test.
This device type shall support static datagrams (see
4.3.2.5)
with data points acc. to
Annex B.
Transmitted data is used for maintenance of the device, not for the alarm itself.
Shall be used only in combination with the sub device type ID11!
b
c
d
e
Table 3
â
Device Types of other OMS end-devices (prepared for OMS-CT)
Device Type
Code
25h
31h
32h
33h
36h
37h
38h
Category
Customer unit (display device)
Communication controller
Unidirectional repeater
Bidirectional repeater
Radio converter (system side)
Radio converter (meter side)
Wired adapter
E
E
E
E
E
E
E
OMS GROUP
27/143
Open Metering System Specification Vol.2
â
Primary Communication
Issue 5.0.1 / 2023-12 (RELEASE)
Table 4
â
Device Types of not certifiable device
Device Type
Code
01h
Category
Oil meter
F
F
F
E
F
-
Steam meter
05h
Compressed air
09h
Bus / System component
Unknown Device Type
Irrigation water meter
Water data logger
0Eh
0Fh
10h
11h
Gas data logger
12h
Gas converter
13h
Calorific value
14h
F
9
F
F
F
-
Dual register (hot/cold) water meter
A/D Converter
17h
19h
Room sensor (e.g. temperature or humidity)
Gas detector
1Bh
1Ch
a
22h to 24h
26h to 27h
29h
Reserved for switching devices
Reserved for customer units
Garbage
-
F
F
-
Reserved for Carbon dioxide
Reserved for environmental meter
2Ah
2Bh to 2Fh
30h
Reserved for system devices
34h to 35h
39h to 3Fh
E
Reserved
40h to FEh
-
-
Not applicable (reserved for wildcard search; refer to [prEN 13757-7:2023],
7.5.4)
FFh
a
Deprecated according to [prEN13757-7:2023]
OMS GROUP
28/143
Open Metering System Specification Vol.2
â
Primary Communication
Issue 5.0.1 / 2023-12 (RELEASE)
3
Address Handling
3.1 M-Bus Address
3.1.1 Overview
The M-Bus defines several types of addressing. They differ between wired M-Bus (see
3.1.2),
wireless M-Bus with link layer frame format A (FFA, see
3.1.3)
and wireless M-Bus with link
layer frame format C (FFC, see
3.1.4)
.
5
The addresses can be handled in different layers, these are:
â¢
â¢
â¢
â¢
the Data Link Layer (DLL)
the Extended Link Layer (ELL)
the Logical Link Control Layer (LLC)
the Transport Layer (TPL).
10
The format of the address Field (A-Field) is different in each of those layers. The addresses
used in the lower layers (DLL, ELL and LLC) are needed for communication purpose whereas
the address in the TPL is used for identification of the (metering) application.
15
3.1.2 Wired M-Bus
3.1.2.1 Primary
Address
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

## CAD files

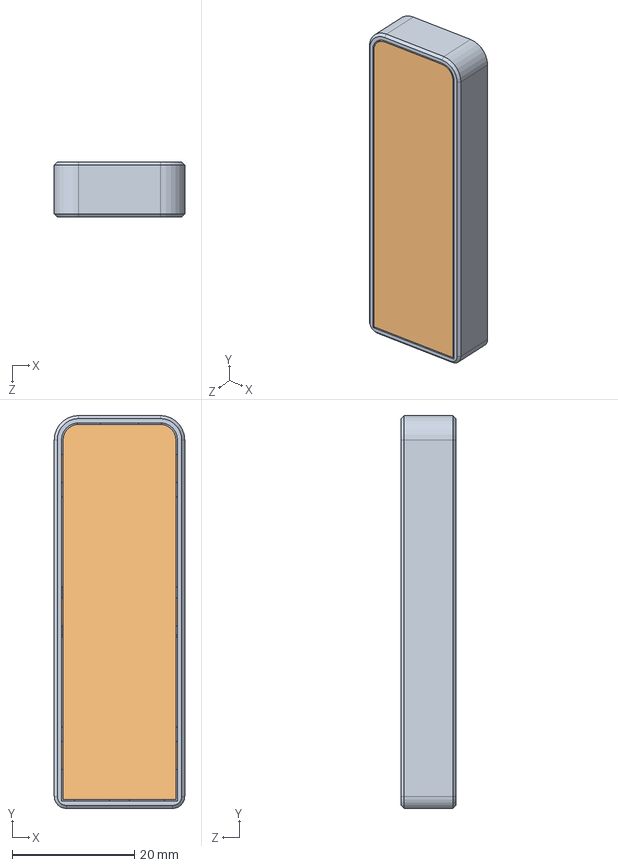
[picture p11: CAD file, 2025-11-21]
CAD/HUB_ASSAMBLY.SLDASM
21.4 x 64.4 x 9.00 mm
HUB_CASE_BASE
HUB_BACK

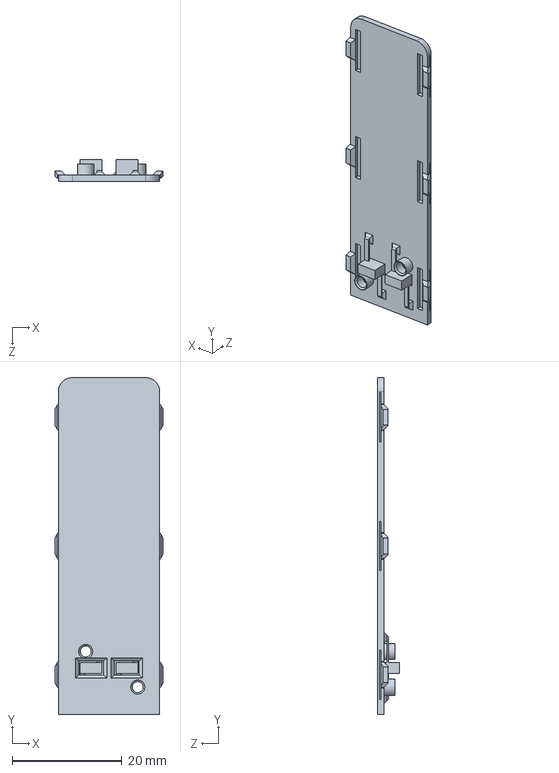
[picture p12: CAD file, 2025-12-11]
CAD/HUB_BACK.SLDPRT
19.8 x 61.5 x 4.00 mm

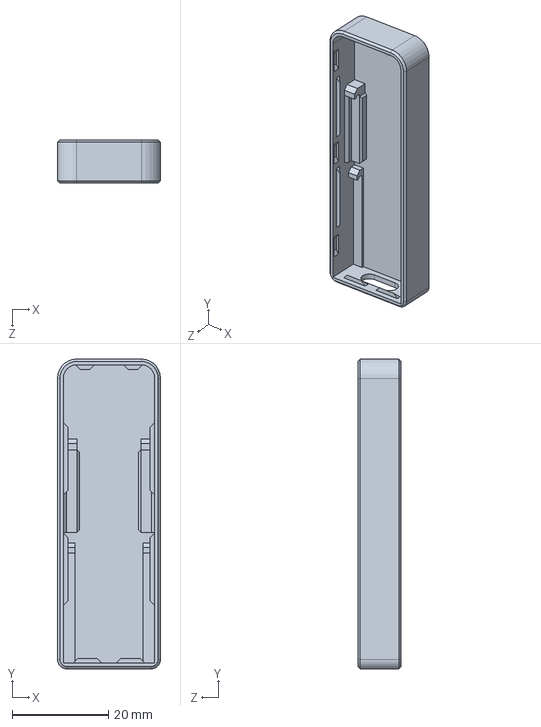
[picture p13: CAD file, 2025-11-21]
CAD/HUB_CASE_BASE.SLDPRT
21.4 x 64.4 x 9.00 mm

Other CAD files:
CAD/HUB_BACK.STL
CAD/HUB_CASE_BASE.STL

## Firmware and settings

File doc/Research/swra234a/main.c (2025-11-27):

/******************************************************************************
    Filename: main.c
******************************************************************************/

#include <hal_types.h>
#include <hal_defs.h>
#include <hal_board.h>
#include <hal_lcd.h>
#include <hal_uart.h>
#include <hal_led.h>
#include <hal_spi.h>
#include <hal_int.h>
#include <hal_mcu.h>
#include <hal_rf.h>
#include <cc2500.h>
#include <stdlib.h>
#include <mbus_packet.h>
#include <tx.h>
#include <rx.h>

#include <tmode_rf_settings.h>
#include <smode_rf_settings.h>

//----------------------------------------------------------------------------------
//  Constants used in this file
//----------------------------------------------------------------------------------

// Radio Mode
#define RADIO_MODE_TX  1
#define RADIO_MODE_RX  2



//----------------------------------------------------------------------------------
//  Variables
//----------------------------------------------------------------------------------

static volatile uint8 radioMode;
static volatile uint8 radioModeSet = FALSE;

static volatile uint8 WMBUSmode;
static volatile uint8 WMBUSmodeSet = FALSE;

static volatile uint8 buttonPushed = FALSE;


// Pin to indicate active or low Power Mode
// Can be removed in a final implementation
const digioConfig pinLPM = {3, 4, BIT4, HAL_DIGIO_OUTPUT, 1};


// TX - Buffers
uint8 TXdata[256];
uint8 TXdataLength = 5;
uint8 TXpacket[291];
uint8 TXbytes[584];

// RX - Buffers
uint8 RXpacket[291];
uint8 RXbytes[584];



//----------------------------------------------------------------------------------
//  Functions
//----------------------------------------------------------------------------------

//----------------------------------------------------------------------------------
//  void myS1buttonISR(void)
//
//  DESCRIPTION:
//    This function is called when the S1 button is pressed.
//    Selects mode of operation the first time it runs.
//    Selects WMBUS mode the second time it runs.
//----------------------------------------------------------------------------------

static void myS1buttonISR(void)
{
  if (!radioModeSet)
  {
      radioMode = RADIO_MODE_RX;
      radioModeSet = TRUE;
      halLcdWriteSymbol(HAL_LCD_SYMBOL_RX, TRUE);
  }
  else if (!WMBUSmodeSet)
  {
      WMBUSmode = WMBUS_SMODE;
      WMBUSmodeSet = TRUE;
      halLcdWriteSymbol(HAL_LCD_SYMBOL_ANT, TRUE);
  }
  buttonPushed = TRUE;
  
 // Simple debouncing logic
 // A final application should use a more advanced version
 halMcuWaitUs(60000); 
 halDigioIntClear(&pinS1);
 
}



//----------------------------------------------------------------------------------
//  void myS2buttonISR(void)
//
//  DESCRIPTION:
//    This function is called when the S2 button is pressed.
//    Selects mode of operation the first time it runs.
//    Selects WMBUS mode the second time it runs.
//----------------------------------------------------------------------------------

static void myS2buttonISR(void)
{
  if (!radioModeSet)
  {
      radioMode = RADIO_MODE_TX;
      radioModeSet = TRUE;
      halLcdWriteSymbol(HAL_LCD_SYMBOL_TX, TRUE);
  }
  else if (!WMBUSmodeSet)
  {
      WMBUSmode = WMBUS_TMODE;
      WMBUSmodeSet = TRUE;
      halLcdWriteSymbol(HAL_LCD_SYMBOL_ANT, TRUE);
  }
  
  buttonPushed = TRUE;

  // Simple debouncing logic                               
  // A final application should use a more advanced version
  halMcuWaitUs(60000); 
  halDigioIntClear(&pinS2);

}



//----------------------------------------------------------------------------------
//  void initData (uint8* pData, uint8 size)
//
//  DESCRIPTION:
//    Set up example user data for a wireless MBUS packet in an array
//
//  ARGUMENTS:  
//    uint8 pData         - Pointer to the array
//    unit8 size          - Size of the array
//----------------------------------------------------------------------------------
static void initData (uint8* pData, uint8 size)
{
  
  // Create a Wireless MBUS packet - Test Only
  // Loop through all possible packet sizes. 
/*  uint8 dataCnt;
  // Fill array with dummy data
  for (dataCnt = 0; dataCnt < size; dataCnt++)
    pData[dataCnt] = dataCnt;
*/
  
  // Create a Wireless MBUS packet with valid data
  pData[0] = 0x0B;
  pData[1] = 0x12;
  pData[2] = 0x43;
  pData[3] = 0x65;
  pData[4] = 0x87;

}



//----------------------------------------------------------------------------------
//  uint8 asciiValue hexToAscii(uint8 hexValue)
//
//  DESCRIPTION:
//    Converts a 4-bit hex value to a ascii character
//
//  ARGUMENTS:  
//    uint8 hexValue      - pointer to the HEX value
//
//  RETURNS:  
//    The ASCII character
//----------------------------------------------------------------------------------
static uint8 hexToAscii(uint8 hexValue)
{
  uint8 asciiValue;
  
  asciiValue = (hexValue & 0x0F);
  
  // If the hex value is [0-9]
  if (asciiValue < 10 )
    asciiValue += 48; // ASCII '0' -> 48 decimal
  
  // Else the hex value is [A-F]
  else 
    asciiValue += 55; // ASCII 'A' -> 65 decimal
  
  return (asciiValue);
  
}




//----------------------------------------------------------------------------------
//  void main(void)
//
//  DESCRIPTION:
//    This is the main entry of the "Wireless MBUS" application. It sets up the board
//    and lets the user select operating mode (RX or TX) by pressing either button
//    S1 (RX) or S2(TX). After selecting operating mode, the user selects Wireless 
//    MBUS mode (Smode or Tmode) by pressing either button S1 (Smode) or S2 (Tmode)
//
//    In TX mode, a wireless MBUS packet is written to the FIFO 
//    every time S2 is pushed. The LCD will be updated every time a new 
//    packet is successfully transmitted. If an error occurs during transmit, 
//    a LED will blink.
//
//    In RX mode, the LCD will be updated every time a new 
//    packet is successfully received. The received packet will also be transmitted
//    over the UART.
//    If an error occurs during reception, a LED will blink.
//----------------------------------------------------------------------------------
void main (void)
{
  
  //------------------------------------------------------------------------------
  // declarations
  //------------------------------------------------------------------------------
  

  // Tranceiver ID
  uint8  id;
  uint8  ver;

  
  //------------------------------------------------------------------------------
  // Initialization
  //------------------------------------------------------------------------------
  
  // Init board and LPM pin
  halDigioConfig(&pinLPM);
  halBoardInit();

  // Reset the CC1101 Tranceiver
  halRfResetChip();

  // Display CC1101 ID and Version
  id  = halRfGetChipId();
  ver = halRfGetChipVer();
  halLcdWriteValue((id << 8) | ver, HAL_LCD_RADIX_HEX, 0);

  // Put radio to sleep
  halRfStrobe(CC2500_SPWD);

  // Set up interrupts for events on the S1 and S2 buttons
  halDigioIntSetEdge(&pinS1, HAL_DIGIO_INT_RISING_EDGE);
  halDigioIntConnect(&pinS1, &myS1buttonISR);
  halDigioIntEnable(&pinS1);

  halDigioIntSetEdge(&pinS2, HAL_DIGIO_INT_RISING_EDGE);
  halDigioIntConnect(&pinS2, &myS2buttonISR);
  halDigioIntEnable(&pinS2);
  
  
  //------------------------------------------------------------------------------
  // Mode Selection
  //------------------------------------------------------------------------------
  
  // Wait for user to select operating mode
  while (!buttonPushed)
  {
    halMcuSetLowPowerMode(HAL_MCU_LPM_3); // Will Enable Interrupts
  }

  buttonPushed = FALSE;
  
  // Wait for user to select WMBUS mode
  while (!buttonPushed)
  {
    halMcuSetLowPowerMode(HAL_MCU_LPM_3); // Will Enable Interrupts
  }

  buttonPushed = FALSE;


  //------------------------------------------------------------------------------
  // TX Mode
  // Data in the TXdata buffer is encoded into a Wireless MBUS packet. 
  // The packet will be encoded (according to mode) and transmitted each time the 
  // S2 button is pushed.    
  //------------------------------------------------------------------------------
      
  if (radioMode == RADIO_MODE_TX)
  {
    uint16 counter;
    uint16 status;

    counter = 0;

    // Create a Wireless MBUS packet
    initData(TXdata, TXdataLength);
    encodeTXPacket(TXpacket, TXdata, TXdataLength);

    // S-mode selected
    if (WMBUSmode == WMBUS_SMODE)
      txInitMode(WMBUS_SMODE, &sModeRfConfig, sModePaTable, sModePaTableLen);
    
    // T-mode selected
    else if (WMBUSmode == WMBUS_TMODE)
      txInitMode(WMBUS_TMODE, &tModeRfConfig, tModePaTable, tModePaTableLen);
      
    while (TRUE)
    {
      // Create a Wireless MBUS packet - Test Only
      // Loop through all possible packet sizes.
/*      initData(TXdata, TXdataLength);
      encodeTXPacket(TXpacket, TXdata, TXdataLength);
      TXdataLength++;
      if (TXdataLength > 0xF5)
       TXdataLength = 0;
*/              
      // Transmit packet
      status = txSendPacket(TXpacket, TXbytes, WMBUSmode);
      
      // Update display if packet successfully transmitted
      if (status == TX_OK)
      {
        // Display number of packets sent
        halLcdWriteValue(++counter, HAL_LCD_RADIX_HEX, 0);  
      }
      
      // Blink a LED if transmission failed
      else
      {
        halLedToggle(1);
        halMcuWaitUs(20000);
        halLedToggle(1);
      }
      
      halDigioIntEnable(&pinS1);
      halDigioIntEnable(&pinS2);
      
      // Await user to start a new transmission
      while (buttonPushed == FALSE)
      {
        // Clear LPM pin to indicate LPM mode  
        halDigioClear(&pinLPM);
        halMcuSetLowPowerMode(HAL_MCU_LPM_3); // Will Enable Interrupts
      }
      
      // The pin interrupts are disabled to ensure:
      // - Avoid triggering a new transmission before 
      // the current is completed. 
      // - Avoid transmission failure due to the debouncing logic. 
      halDigioIntDisable(&pinS1);
      halDigioIntDisable(&pinS2);
      buttonPushed = FALSE;

    }
  }
    
    
  //------------------------------------------------------------------------------
  // RX mode 
  // Initialize the receiver and wait for a packet to be received. 
  // When a complete packet received, the packet is decoded.
  // The LCD display will be updated if 
  // - No data decoding errors
  // - No CRC errors
  // - No RX errors 
  //------------------------------------------------------------------------------
  
  else if (radioMode == RADIO_MODE_RX)
  {
    uint16 counter;
    uint16 status;
    counter = 0;
    
    // - Initialize receiver -
    // Send a text sting over the UART
    halUartWrite( "WIRELESS MBUS PACKET RECEIVED\r\n", 31);
    
    // S-mode selected
    if (WMBUSmode == WMBUS_SMODE)
      rxInitMode(WMBUS_SMODE, &sModeRfConfig, sModePaTable, sModePaTableLen);

    // T-mode selected
    else if (WMBUSmode == WMBUS_TMODE)
      rxInitMode(WMBUS_TMODE, &tModeRfConfig, tModePaTable, tModePaTableLen);
    
    // - Indicate status
    while (TRUE)
    {
      // Await packet received
      status = rxRecvPacket(RXpacket, RXbytes, WMBUSmode); 

       // Update display if packet successfully received and decoded
      if (status == PACKET_OK)
      {
        // Display number of packets received
        halLcdWriteValue(++counter, HAL_LCD_RADIX_HEX, 0);
        
        // Send the received Wireless MBUS packet to the UART
        // The HEX values are converted to ASCII characters so the that 
        // HyperTerminal can be used.
        int i;
        uint8 asciiChar;

        for (i=0; i < packetSize(RXpacket[0]); i++)
        {
          asciiChar = hexToAscii((RXpacket[i] >> 4));
          halUartWrite( &asciiChar, 1);
          asciiChar = hexToAscii(RXpacket[i]);
          halUartWrite( &asciiChar, 1);

          // Space character
          halUartWrite( " ", 1);
        }          
        
        // 2x End of line 
        halUartWrite( "\r\r\n\n", 4);
      }

      // Blink led if receive failed
      else
      {
        halLedToggle(1);
        halMcuWaitUs(20000);
        halLedToggle(1);
      }
    }
  }   
}

  
/***********************************************************************************
  Copyright 2008 Texas Instruments Incorporated. All rights reserved.

  IMPORTANT: Your use of this Software is limited to those specific rights
  granted under the terms of a software license agreement between the user
  who downloaded the software, his/her employer (which must be your employer)
  and Texas Instruments Incorporated (the "License").  You may not use this
  Software unless you agree to abide by the terms of the License. The License
  limits your use, and you acknowledge, that the Software may not be modified,
  copied or distributed unless embedded on a Texas Instruments microcontroller
  or used solely and exclusively in conjunction with a Texas Instruments radio
  frequency transceiver, which is integrated into your product.  Other than for
  the foregoing purpose, you may not use, reproduce, copy, prepare derivative
  works of, modify, distribute, perform, display or sell this Software and/or
  its documentation for any purpose.

  YOU FURTHER ACKNOWLEDGE AND AGREE THAT THE SOFTWARE AND DOCUMENTATION ARE
  PROVIDED “AS IS” WITHOUT WARRANTY OF ANY KIND, EITHER EXPRESS OR IMPLIED,
  INCLUDING WITHOUT LIMITATION, ANY WARRANTY OF MERCHANTABILITY, TITLE,
  NON-INFRINGEMENT AND FITNESS FOR A PARTICULAR PURPOSE. IN NO EVENT SHALL
  TEXAS INSTRUMENTS OR ITS LICENSORS BE LIABLE OR OBLIGATED UNDER CONTRACT,
  NEGLIGENCE, STRICT LIABILITY, CONTRIBUTION, BREACH OF WARRANTY, OR OTHER
  LEGAL EQUITABLE THEORY ANY DIRECT OR INDIRECT DAMAGES OR EXPENSES
  INCLUDING BUT NOT LIMITED TO ANY INCIDENTAL, SPECIAL, INDIRECT, PUNITIVE
  OR CONSEQUENTIAL DAMAGES, LOST PROFITS OR LOST DATA, COST OF PROCUREMENT
  OF SUBSTITUTE GOODS, TECHNOLOGY, SERVICES, OR ANY CLAIMS BY THIRD PARTIES
  (INCLUDING BUT NOT LIMITED TO ANY DEFENSE THEREOF), OR OTHER SIMILAR COSTS.

  Should you have any questions regarding your right to use this Software,
  contact Texas Instruments Incorporated at www.TI.com.
***********************************************************************************/

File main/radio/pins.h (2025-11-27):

// Pin and SPI host mapping for CC1101 on ESP32-C3
#pragma once

#include "driver/spi_common.h"
#include "driver/gpio.h"

#define CC1101_SPI_HOST      SPI2_HOST
#define CC1101_PIN_MISO      GPIO_NUM_5
#define CC1101_PIN_MOSI      GPIO_NUM_6
#define CC1101_PIN_SCLK      GPIO_NUM_4
#define CC1101_PIN_CS        GPIO_NUM_7
#define CC1101_PIN_GDO0      GPIO_NUM_2  // FIFO threshold / RX FIFO event
#define CC1101_PIN_GDO2      GPIO_NUM_3  // Sync/packet done

typedef struct
{
    spi_host_device_t host;
    gpio_num_t miso;
    gpio_num_t mosi;
    gpio_num_t sclk;
    gpio_num_t cs;
    gpio_num_t gdo0;
    gpio_num_t gdo2;
} cc1101_pin_config_t;

static inline cc1101_pin_config_t cc1101_default_pins(void)
{
    cc1101_pin_config_t pins = {
        .host = CC1101_SPI_HOST,
        .miso = CC1101_PIN_MISO,
        .mosi = CC1101_PIN_MOSI,
        .sclk = CC1101_PIN_SCLK,
        .cs = CC1101_PIN_CS,
        .gdo0 = CC1101_PIN_GDO0,
        .gdo2 = CC1101_PIN_GDO2,
    };
    return pins;
}

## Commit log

2025-11-21 Implement Leitfaden-based CC1101 wM-Bus pipeline
    * replace CC1101 config with the T-mode register table (sync word, AGC, FSCAL) and add runtime SCAL after resets
    * add wmbus_receiver module to decode 3-of-6 frames, feed the existing parser, and expose frames via a callback
    * update app_main to hand CC1101 packets to the receiver instead of logging raw bytes
    * implement software length handling per Leitfaden (decode initial 3 bytes, respect L-field, drop invalid headers)
    * harden RX-mode recovery with SIDLE/SFRX/SRX and full reinit, tone down CC1101 logging to debug level, and document the changes in Dev-Log
    [HUB_ASSAMBLY.SLDASM, HUB_BACK.SLDPRT, HUB_BACK.STL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]
2025-11-26 refactor: Improve SPI transaction initialization and enhance RX handling logic
2025-11-27 Refactor wM-Bus T-mode RX handling and introduce pipeline structure
    - Moved RX handling logic from rx.c to a new pipeline.c file for better organization.
    - Introduced a new pipeline.h header to define the RX pipeline interface and structures.
    - Updated packet encoding and decoding functions to improve clarity and maintainability.
    - Enhanced error handling and logging for RX events.
    - Removed legacy rx.c and rx.h files to streamline the codebase.
    - Added support for configurable RX parameters such as sensitivity and sync mode.
    [log.csv]
2025-11-28 feat: Add device type lookup functionality for wM-Bus packets
2025-11-28 feat: Add SVG icons for cloud, podcast, sensors, shield, trash, and wifi
2025-12-01 feat: Enhance packet handling with additional device type information and improved UI for packet display
2025-12-01 feat: Implement layered parsing for wM-Bus frames with TPL and ELL metadata handling
2025-12-02 feat: Implement collapsible sections for network, backend, whitelist, and radio settings
    - Added toggle functionality for collapsible cards in the settings UI.
    - Updated HTML structure to include card heads and bodies for better organization.
    - Enhanced CSS styles for collapsible buttons and card layouts.
    - Improved JavaScript functions to handle card toggling and state management.
    refactor: Enhance packet modal display with structured layers
    - Refactored packet modal to display parsed data in structured layers (DLL, TPL, ELL, AFL, Meta).
    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
2025-12-11 feat: Implement status LED handling with various patterns and connection indicators
2025-12-11 Update Enclosure
    [HUB_BACK.SLDPRT, HUB_BACK.STL]
2025-12-11 fix: Update image reference for enclosure with lid in documentation
2025-12-17 feat: Enhance wM-Bus frame parsing with extended TPL configuration and improved CI classification
2025-12-17 feat: Add raw hex display and copy functionality for logical frames in packet modal
2026-01-08 refactor: Update firmware section to reflect complete data flow from gateway to backend
